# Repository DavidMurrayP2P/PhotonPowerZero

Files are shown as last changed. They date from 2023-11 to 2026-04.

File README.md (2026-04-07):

# PhotonPowerZero

The Photon Power Zero project aims to build an ecosystem of electronics, code, BoM and 3D printable parts that make it as easy as possible to go from a Raspberry Pi Zero proof of concept, sitting on someone's desk, to an outdoor deployment. The first 50 boards sold out through this [Kickstarter](https://www.kickstarter.com/projects/packets2photons/photon-power-zero).

You can find the user docs, showing you how to get started with the Photon Power Zero, and the design decisions around the board here:
* [USERDOCS](USERDOCS.md) 
* [6W SOLAR BUILD](FDM/6W_Voltaic_Panel_to_Multicomp_enclosure/README.md)
* [10W SOLAR BUILD](FDM/10W_Voltaic_Panel_to_Multicomp_enclosure/README.md)
* [REDUCING_ENERGY_CONSUMPTION](REDUCING_ENERGY_CONSUMPTION.md)
* [DESIGN_AND_DECISIONS](DESIGN_AND_DECISIONS.md)
* [LIPO_PURCHASING](LIPO_PURCHASING.md)

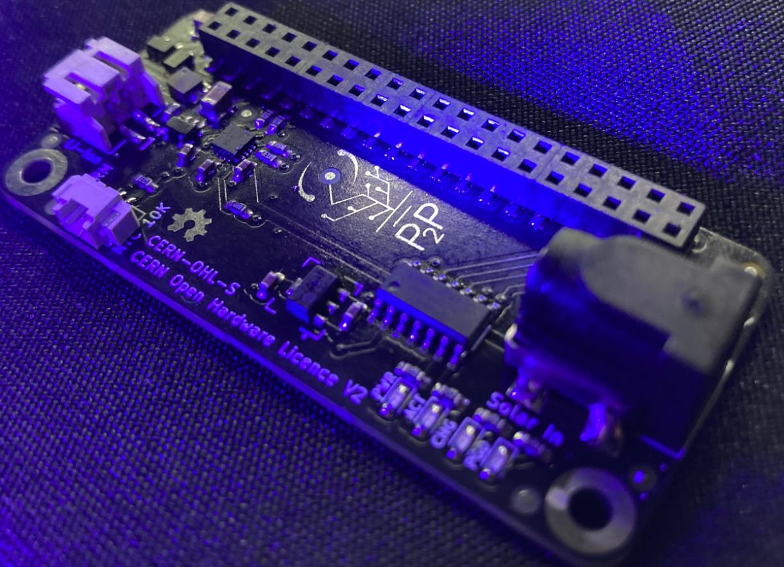
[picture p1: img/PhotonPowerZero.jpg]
Title
 <p style="text-align:center; font-style:italic;">Photon Power Zero Board</p>

The project is more than just the Photon Power Zero board. I want to create and share all components to make deploying a Raspberry Pi Zero outdoors as easy as possible. You can collaborate on the project and recieve support through the [Discord](https://discord.gg/BphNWmj6Xg)

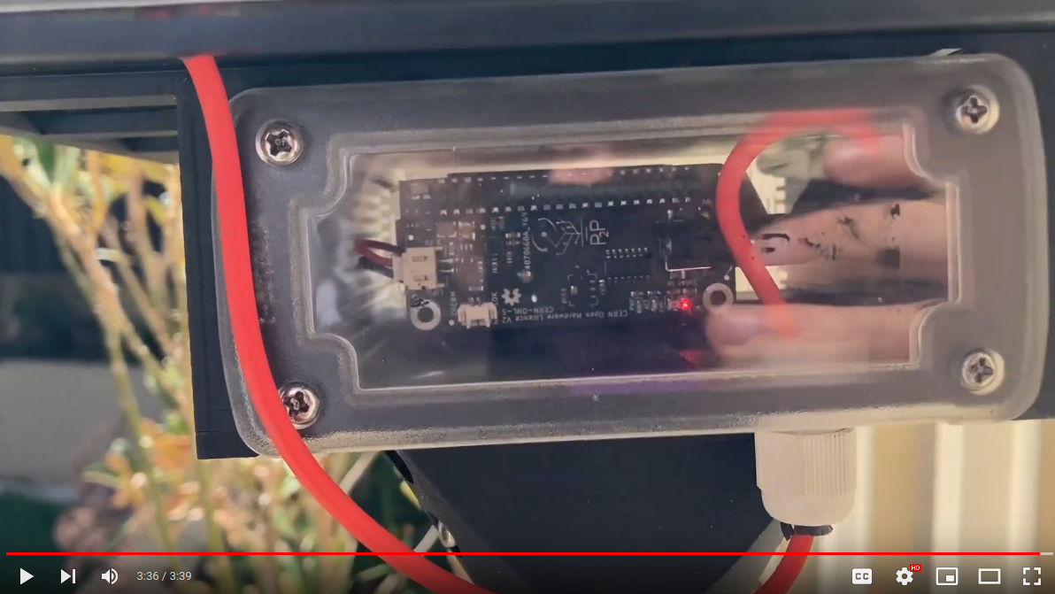
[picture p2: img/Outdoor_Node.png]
Video Thumbnail
 <p style="text-align:center; font-style:italic;">Youtube Video describing the Project and the goals</p>

As an open-source project, you can find the code for the Photon Power Zero and the Raspberry Pi, the Kicad PCB files and the FDM 3D printing files below
* [Code](Code)
* [PCBs](PCBs)
* [FDM (3D Print Files)](FDM)

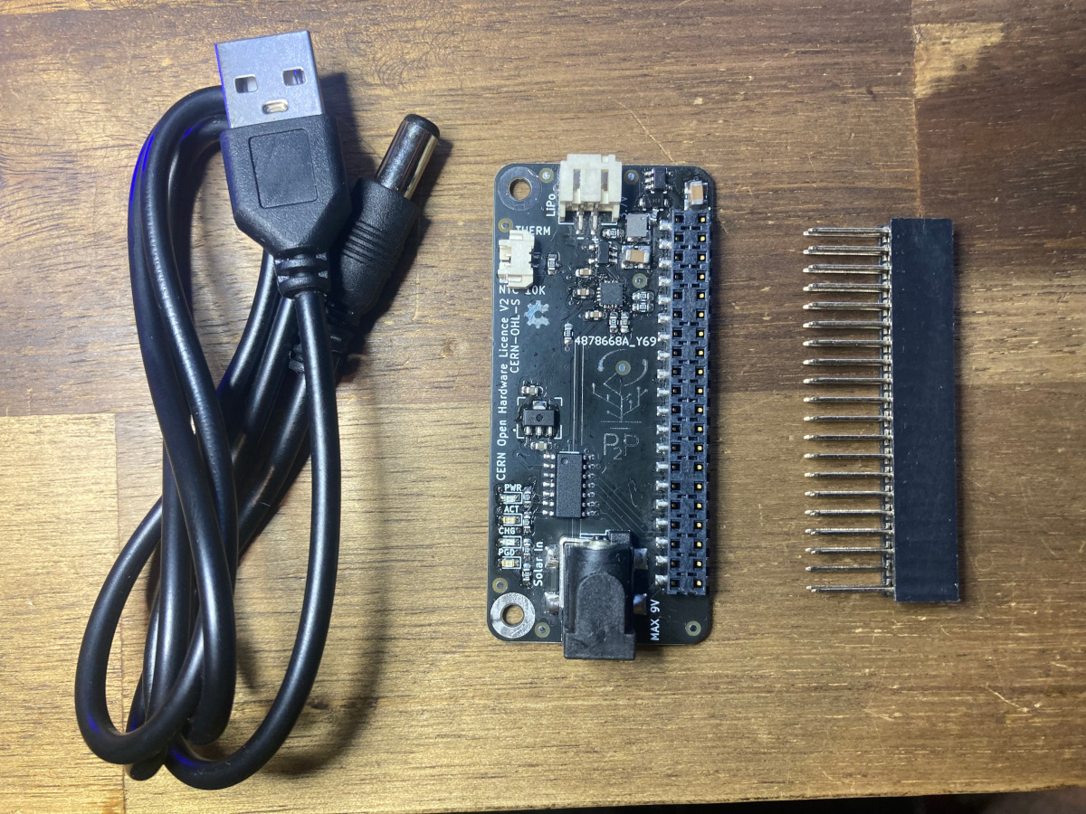
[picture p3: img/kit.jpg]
Production Kit Title

<p style="text-align:center; font-style:italic;">Production kit</p>

Note that the Photon Power Zero does not come with a LiPo battery. You need to self-source your battery and carefully read our [LIPO_PURCHASING](LIPO_PURCHASING.md) guide.

We have tested the solar panels from [Voltaic Systems](https://voltaicsystems.com/). We used the 6-watt 6-volt panels during testing, but now recommend the the 9-10-watt panels specified in the [10W SOLAR BUILD](FDM/10W_Voltaic_Panel_to_Multicomp_enclosure/README.md)

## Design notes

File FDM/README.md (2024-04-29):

# Photon Power Zero Mounts and Cases

The purpose of this section is to provide ways to mount your Raspberry Pi Zero and Photon Power Zero as well as provide mounts inside cases, batteries, solar panels, cameras and common acessories. 

In each of these subdirectories, there should be links to 3D printer files as well as instructions on how to print, and links to what should be purchased. 

The hope is that, as a community, we can suport a wide range of solar panels, batteries and water proof enclosures.

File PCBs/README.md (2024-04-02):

# PhotonPowerZero PCB

Title <p style="text-align:center; font-style:italic;">Photon Power Zero Board</p>

### BOM ###
 - 1k	4	https://www.digikey.com.au/en/products/detail/yageo/RC0603FR-071KL/726843
 - 10k	5	https://www.digikey.com.au/en/products/detail/yageo/RC0603JR-0710KL/726700
 - 1.13k	1	https://www.digikey.com.au/en/products/detail/yageo/RC0603FR-071K13L/726849
 - 1.18k	1	https://www.digikey.com.au/en/products/detail/yageo/RC0603FR-071K18L/726851
 - 10uf	6	https://www.digikey.com.au/en/products/detail/yageo/CC0805ZKY5V6BB106/2103093
 - Red 0603 LEDs	2	https://www.digikey.com.au/en/products/detail/liteon/LTST-C191KRKT/386837
 - Green 0603 LEDs	2	https://www.digikey.com.au/en/products/detail/rohm-semiconductor/SML-D12M8WT86/1641797
 - 100uf 1210	2	https://www.digikey.com.au/en/products/detail/samsung-electro-mechanics/CL31A107MQHNNNE/3887440
 - 2.2 µH Shielded Inductor 2.5 A 90mOhm Max 1210	1	https://www.digikey.com.au/en/products/detail/delta-electronics-cyntec/HMLE32251B-2R2MS/9761439
 - ATtiny84-SSFR	1	https://www.digikey.com.au/en/products/detail/microchip-technology/ATTINY84A-SSFR/3789533
 - AP2161-WG	1	https://www.digikey.com.au/en/products/detail/diodes-incorporated/AP2161WG-7/1964659
 - Diode 60 V 2A Surface Mount SOD-123F	1	https://www.digikey.com.au/en/products/detail/smc-diode-solutions/SK34A/6023036
 - REG_MCP1700T-3602E/MB	1	https://www.digikey.com.au/en/products/detail/microchip-technology/MCP1700T-3002E%2FMB/3622376
 - bq2407	1	https://www.digikey.com.au/en/products/detail/texas-instruments/BQ24074RGTR/2047269
 - TPS613222A	1	https://www.digikey.com.au/en/products/detail/texas-instruments/TPS613222ADBVT/9371270
 - SMT_Solar_barrel	1	https://www.aliexpress.com/item/32730853300.html
 - JST_S2B-PH-SM4-TB_LF__SN_	1	https://www.aliexpress.com/item/4000906681691.html
 - Barrel Jack to USB	1	https://www.aliexpress.com/item/1005003706471183.html
 - Samtech Pi headers	1	https://www.samtec.com/ HLE-120-02-L-DV-BE-A-K
 - Raspberry Pi header extender	1	https://www.aliexpress.com/item/4001267078607.html

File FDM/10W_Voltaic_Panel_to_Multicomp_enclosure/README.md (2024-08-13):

# 10W Voltaic Solar Panel to MULTICOMP PRO MC002194 enclosure

This guide shows you how to build a 10W outdoor solar mount for your Raspberry Pi Zero and Photon Power Zero.

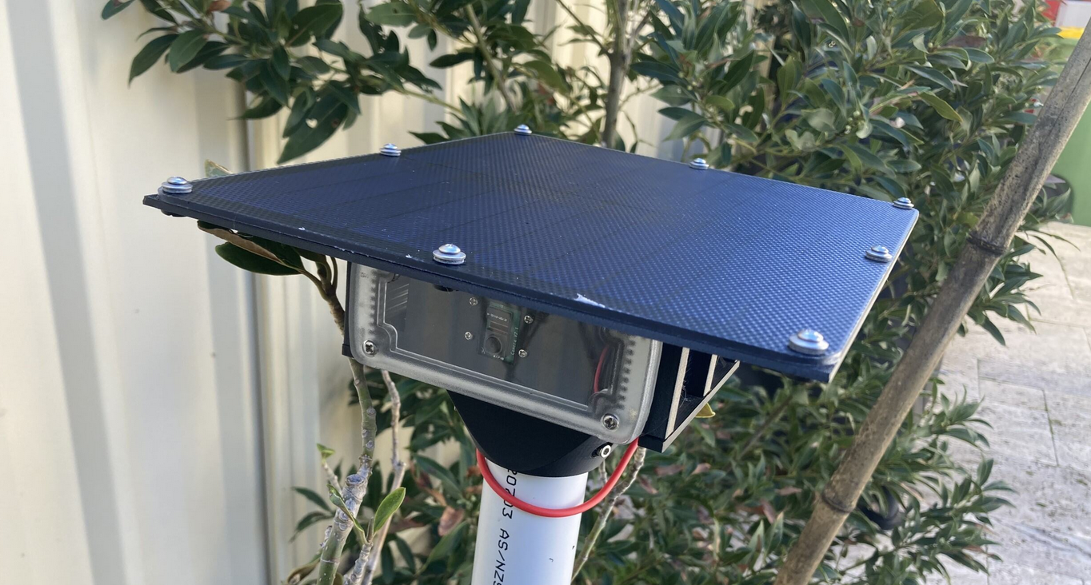
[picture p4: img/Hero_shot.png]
<p style="text-align:center; font-style:italic;">Finished construction</p>

This is a panel mount for Voltaic's 10W solar panel. These have been printed and tested using ABS, but other materials may work well too. ASA will almost certainly be as good. I also think that PETG will likely work, but this is untested. There is a [Bill of Materials (BOM)](#bill-of-materials-bom) which links to multiple sources, at the bottom of the page. All the files required for printing can be found here [10W Voltaic Panel to Multicomp enclosure](https://github.com/DavidMurrayP2P/PhotonPowerZero/tree/main/FDM/10W_Voltaic_Panel_to_Multicomp_enclosure).

The image below shows the entire stet of printed parts but they must be printed in multiple parts. How many parts will depend on your printer size.

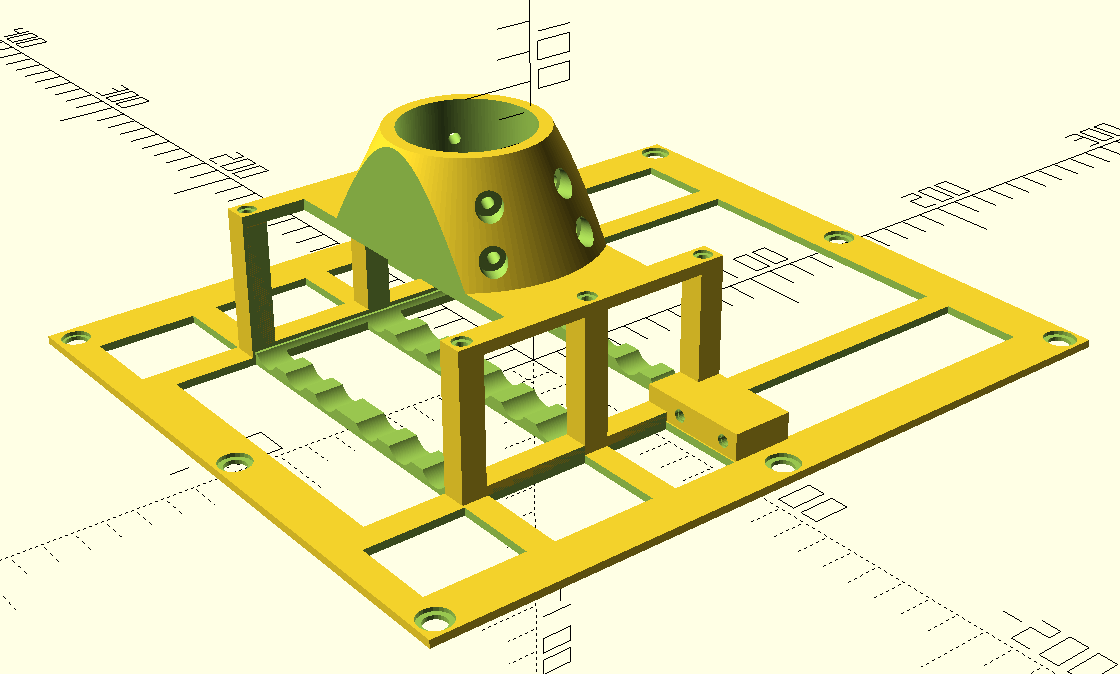
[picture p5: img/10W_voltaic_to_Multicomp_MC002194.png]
<p style="text-align:center; font-style:italic;">Connect the 10W volatic Panel to the Mutlicomp MC002194 Enclosure and 25mm OD PVC Pipe. This is obviously printed in two parts. 

The image above shows what the mount looks like
Title<p style="text-align:center; font-style:italic;">Finished construction
 but you can print it in two parts. This should be divided up for you already in the files pole_mount.stl and Panel_Mount_10W.stl

Most people will need to print the Panel_Mount_10W.stl in two parts: Panel_Mount_10W_1st_half.stl and Panel_Mount_10W_2nd_half.stl

When you print these parts, you will need to sink the brass heat set inserts:

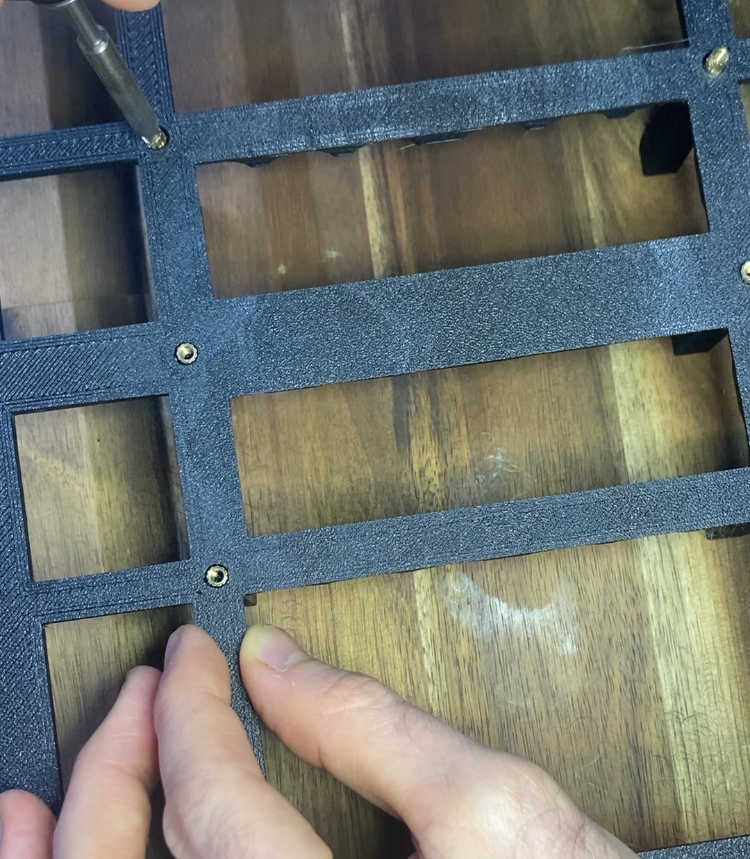
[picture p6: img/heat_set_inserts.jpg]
<p style="text-align:center; font-style:italic;">You will need to put 6 heat set inserts in the bottom side of the panel mount

After you do this you will most likely need to clean out the holes. I like to put the m3 screws in on the opposite side to force any plastic out and clear the path.

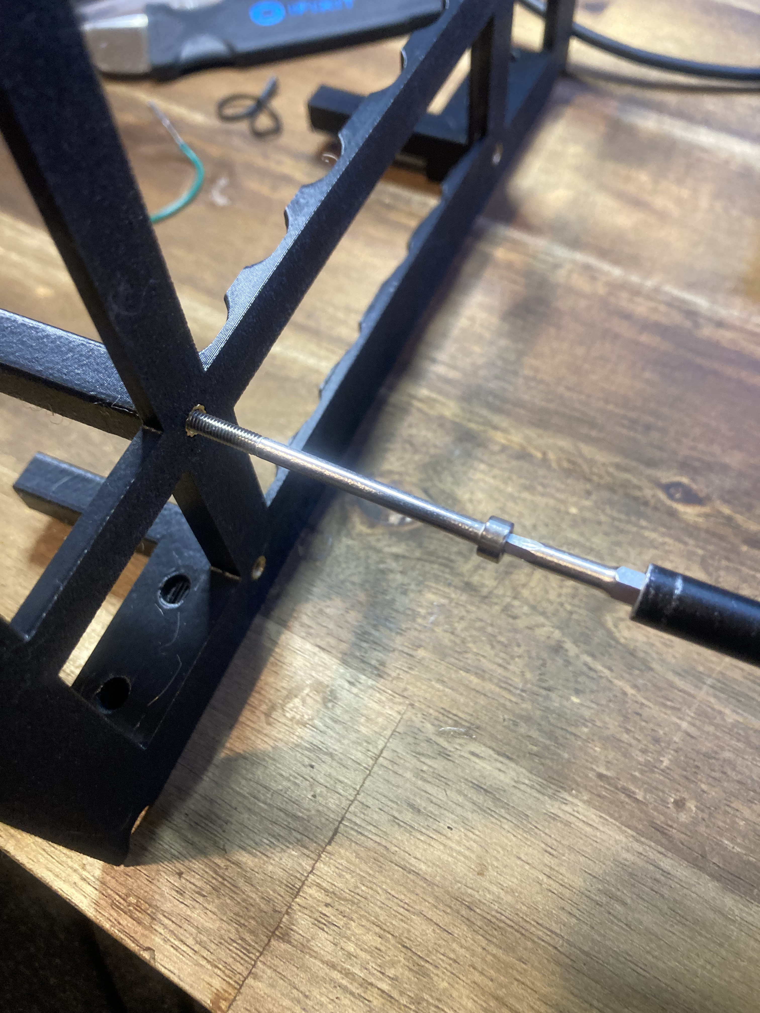
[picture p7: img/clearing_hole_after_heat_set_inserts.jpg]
<p style="text-align:center; font-style:italic;">Make sure you clear the holes by putting m3 screws in the wrong way around.

You have likely printed the panel mount in two parts. They screw together with M3 heat set inserts and M3 screws.

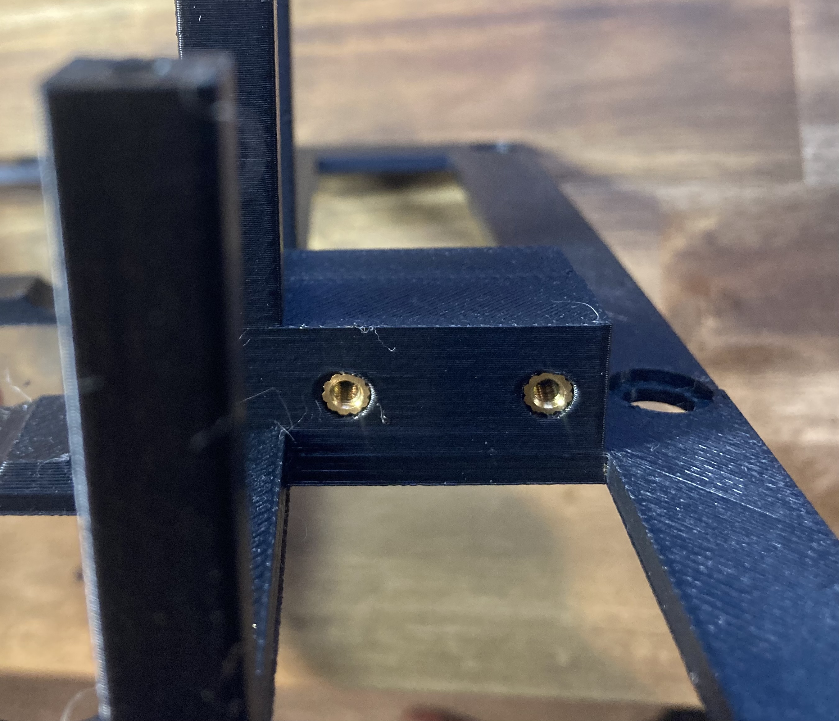
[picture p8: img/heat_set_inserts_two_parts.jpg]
<p style="text-align:center; font-style:italic;">Heat set inserts for the two parts

You can then srcew the two parts together:

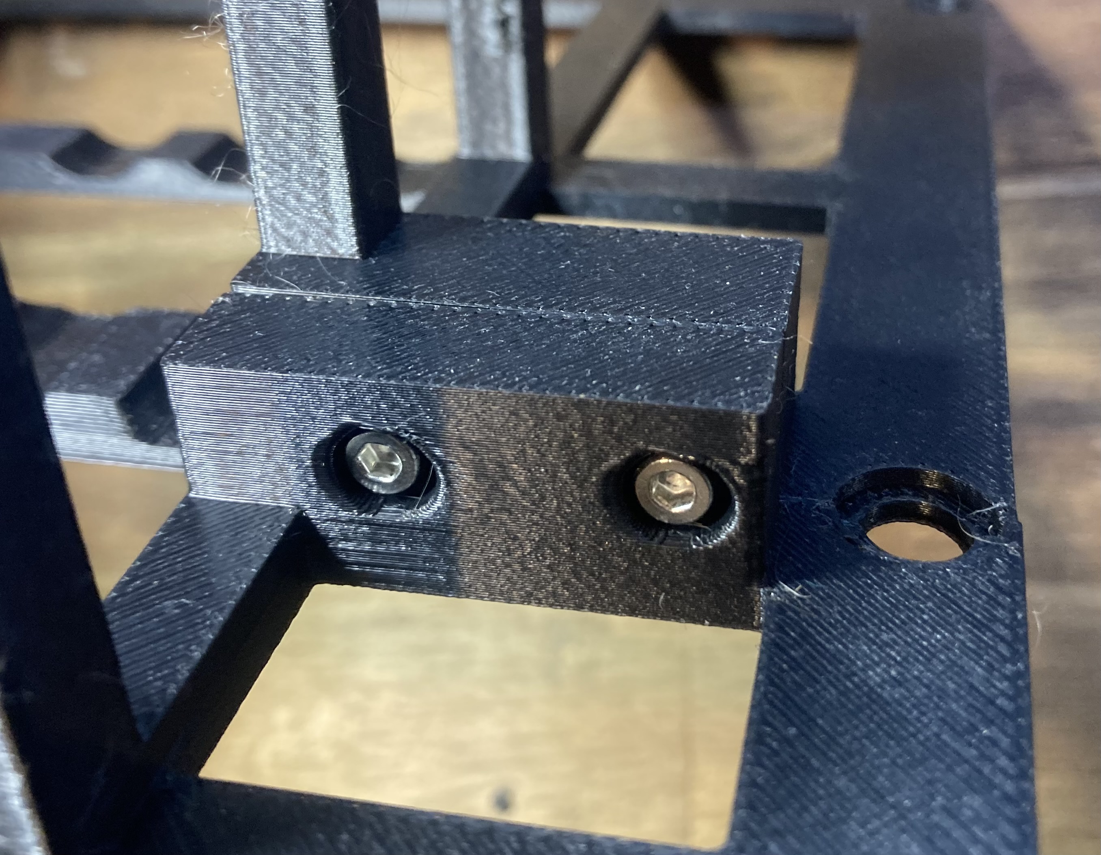
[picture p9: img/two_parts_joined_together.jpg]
<p style="text-align:center; font-style:italic;">Screw the two parts together

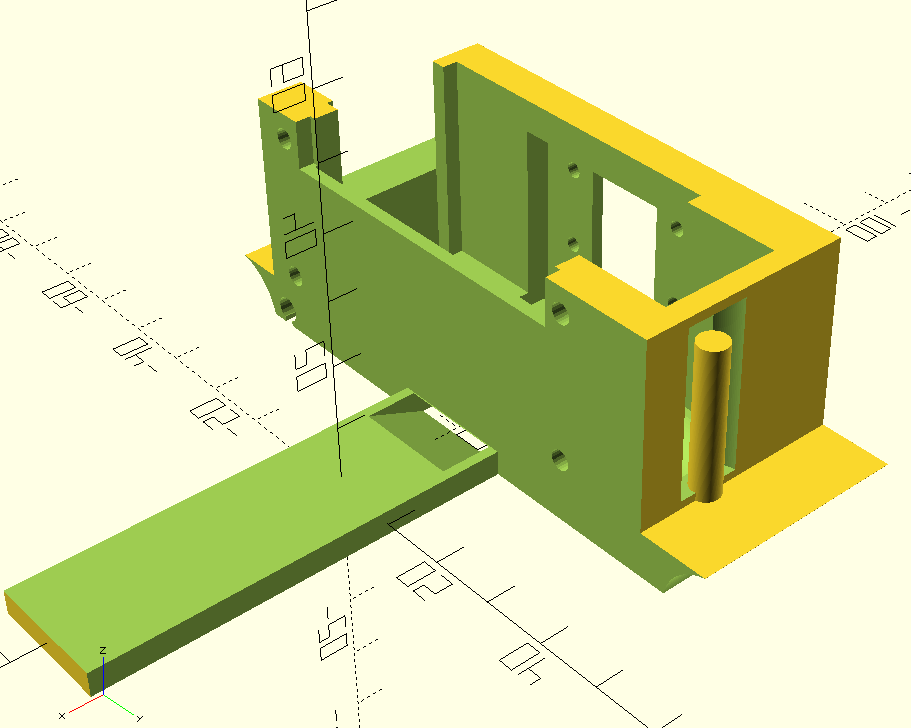
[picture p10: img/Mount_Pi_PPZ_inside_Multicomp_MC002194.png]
<p style="text-align:center; font-style:italic;">Mount inside the Multicomp MC002194 Enclosure

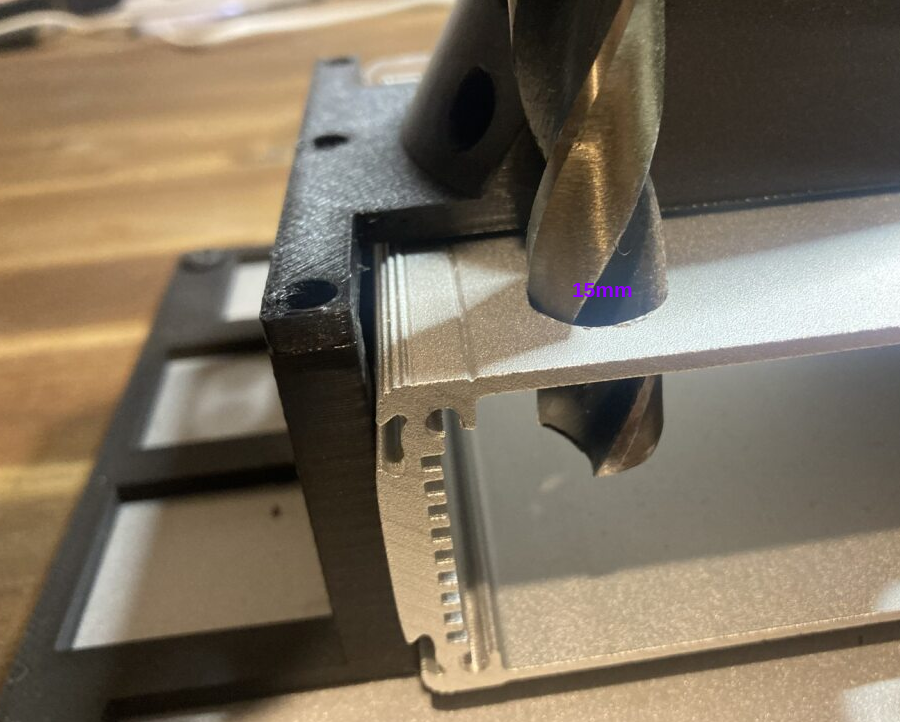
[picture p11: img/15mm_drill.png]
<p style="text-align:center; font-style:italic;">You need to drill a 15mm hole in the aluminium and use a Waterproof cable gland PG-9. Obviously you don't drill this hole on top of the solar pannel.

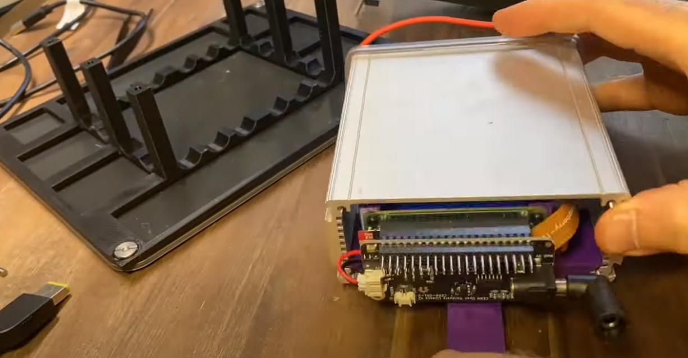
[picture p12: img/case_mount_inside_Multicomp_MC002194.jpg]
<p style="text-align:center; font-style:italic;">The case mount goes inside the multicomp

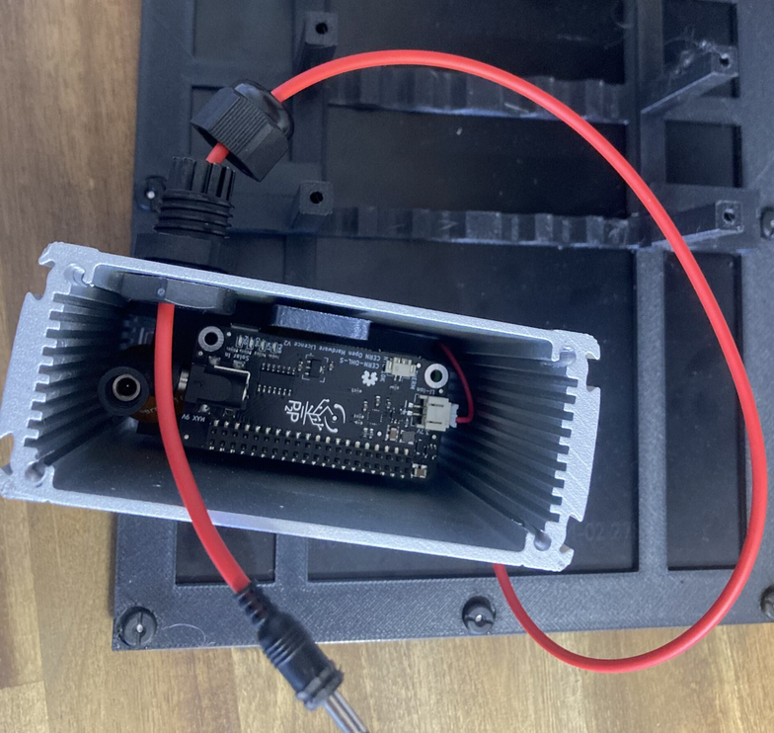
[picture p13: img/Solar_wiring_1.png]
<p style="text-align:center; font-style:italic;">Wiring the solar

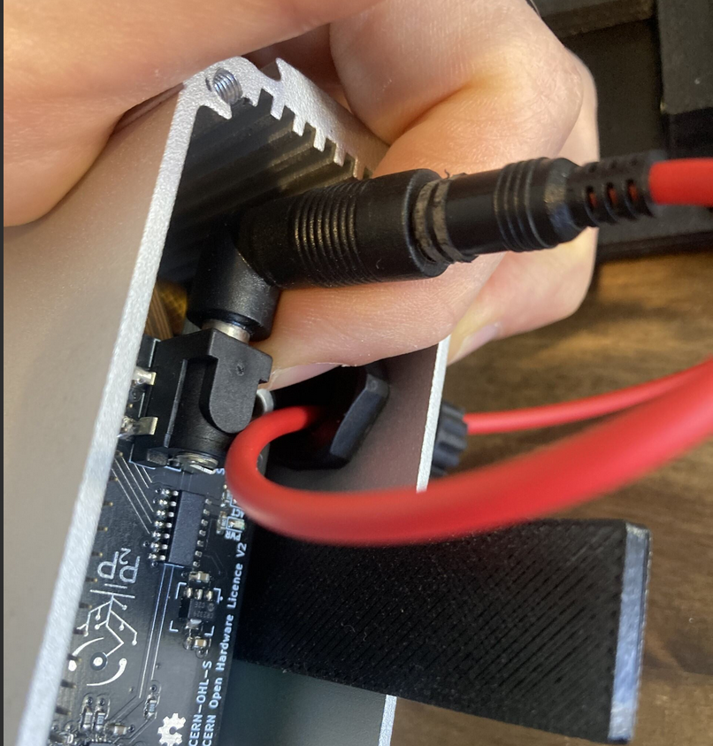
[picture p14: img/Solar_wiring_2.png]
<p style="text-align:center; font-style:italic;">Provide support for the connector while you plug it in

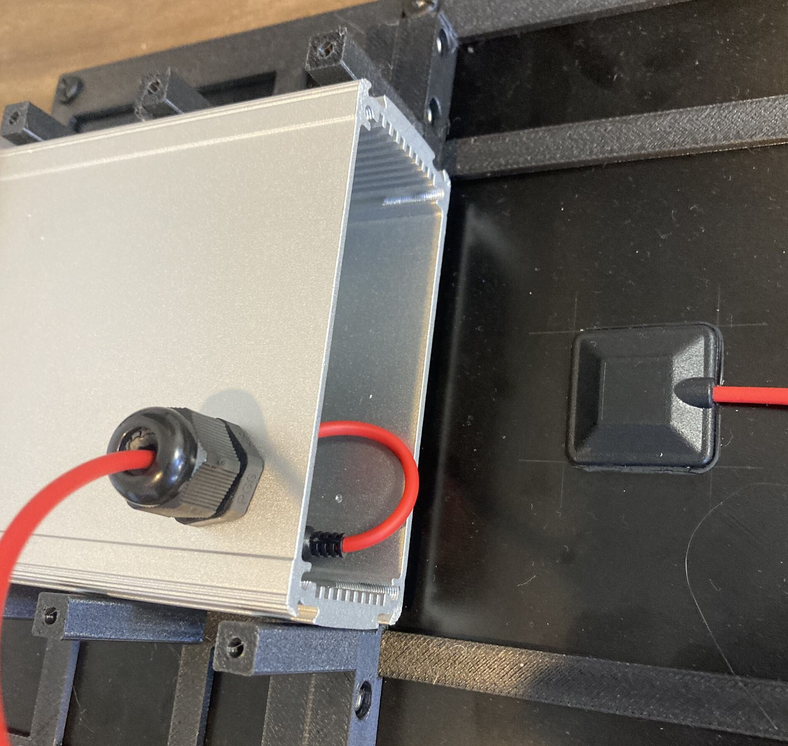
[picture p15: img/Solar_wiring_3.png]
<p style="text-align:center; font-style:italic;">Tighten the PG-9 Gland

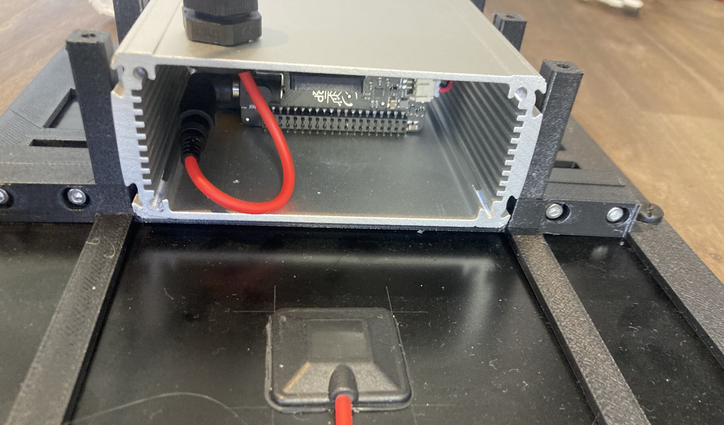
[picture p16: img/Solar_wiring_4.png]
<p style="text-align:center; font-style:italic;">In the next step we will screw the plastic end on

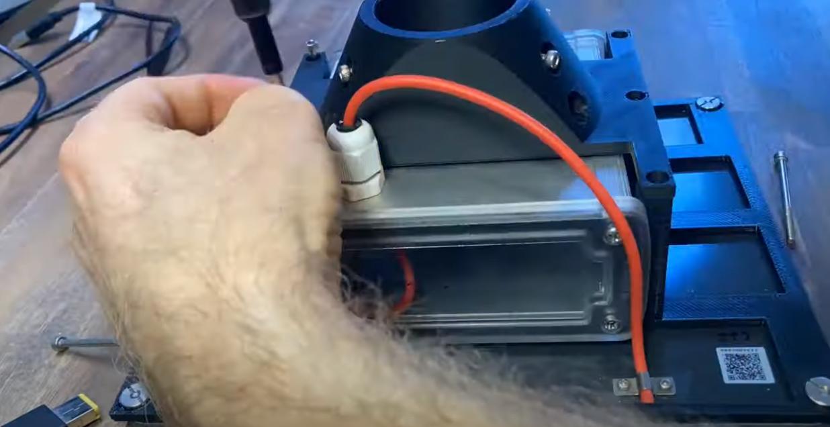
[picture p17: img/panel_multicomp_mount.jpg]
<p style="text-align:center; font-style:italic;">Physically Fitting it together, put a 25mm PVC pipe to connect the structure to the soil or a Ubolt clamp
panel_multicomp_mount.jpg

Use 50mm M3 screws to put screw pole_mount.stl into the panel mount.

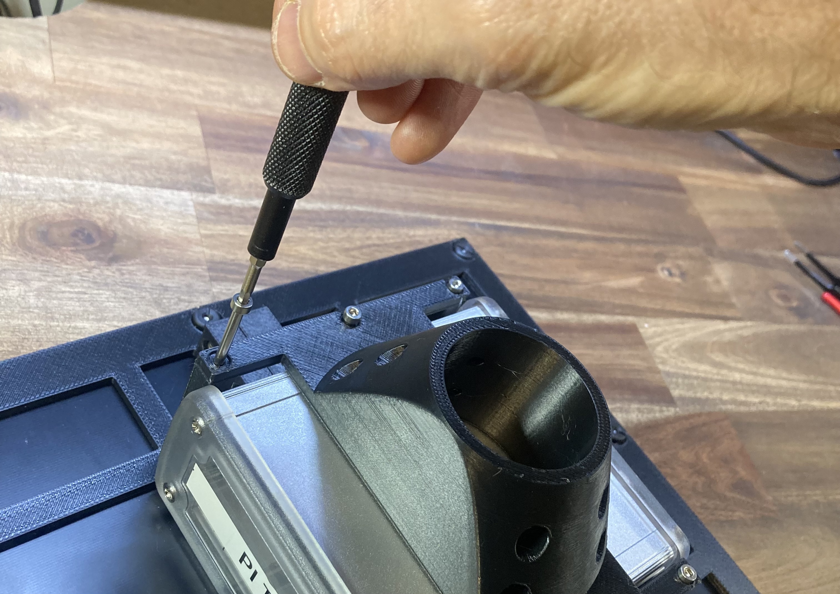
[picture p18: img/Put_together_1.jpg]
<p style="text-align:center; font-style:italic;">Use 50mm M3 screws to put screw pole_mount.stl into the panel mount.

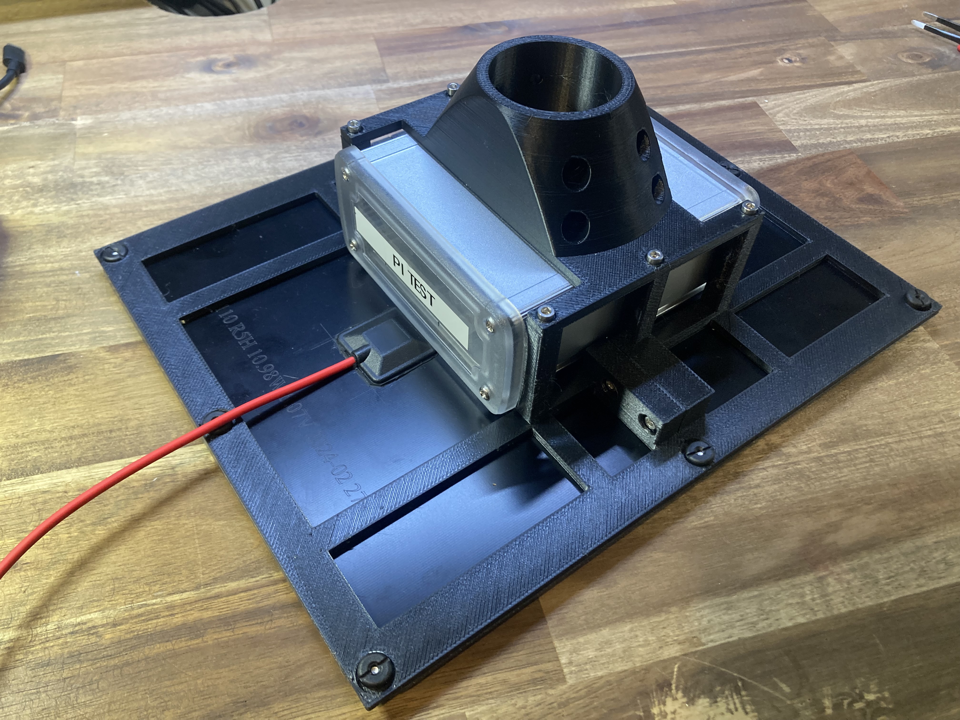
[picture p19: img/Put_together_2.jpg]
<p style="text-align:center; font-style:italic;">Screwed together

## Bill of Materials (BOM)

#### MULTICOMP PRO MC002194 
Metal Enclosure, Small, Extruded Aluminium, 51.6 mm, 119 mm, 115.1 mm Links:
- https://www.jaycar.com.au/aluminium-enclosure-with-clear-ends/p/HB6294
- https://il.farnell.com/multicomp/mc002194/multipurpose-enclosure-alum-silver/dp/2830527
- https://www.newark.com/multicomp-pro/mc002194/enclosure-4-53-x-4-69-x-2-03/dp/57AC8361
- https://www.devicemart.co.kr/goods/view?no=12072777
- https://dk.farnell.com/en-DK/multicomp/mc002194/multipurpose-enclosure-alum-silver/dp/2830527

#### Fixing hardware 

These are for mounting the Raspberry Pi Zero to the case inside the enclosure
 - 4x M2.5 heat set inserts like https://www.aliexpress.com/item/1005004535859664.html
 - M2.5 Mounting hardware https://www.aliexpress.com/item/1005004275784627.html
  - Waterproof Cable Gland https://core-electronics.com.au/cable-gland-pg-9-size-0-158-to-0-252-cable-diameter-pg-9.html OR https://www.adafruit.com/product/761
  
These are for bolting pole_mount.stl and Panel_Mount_10W.stl together. 
  -  6 x M3 heat set inserts OD 5mm Length ~8mm https://www.aliexpress.com/item/1005004535859664.html - These go on the underside of the panel fitting
 - 6 x M3 50mm Staintelss steel hex bolt https://www.thefastenerfactory.com.au/stainless-steel-hex-socket-head-cap-screw-m3-x-50mm-100pc

#### 10W Voltaic Panel

 - Solar Panel https://voltaicsystems.com/10-watt-panel-etfe/ OR https://www.adafruit.com/product/5369 OR https://core-electronics.com.au/5v-10w-solar-panel-etfe-voltaic-p110.html
 - Right angled Female 3.5x1.1mm - 5.5x2.1mm: https://voltaicsystems.com/A106 or https://www.adafruit.com/product/4287
 - If you get an EFTE panel you need to get ETFE Panel Screw & Washer Set https://voltaicsystems.com/mount-set-etfe/ these are 4-40 but an M3 should work

## Finished Construction

The 25mm PVC pipe can go in the ground or you could use a UBolt. You can modify the scad to support any size round post that you like.

Title<p style="text-align:center; font-style:italic;">Finished construction

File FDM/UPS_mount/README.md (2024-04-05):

# Photon Power Zero 3D Prints 

All of these Parts are designed to be printed in ABS or better. You may print is PLA if your use case is indoor only but otherwise, the reccomendation is ABS.

## Indoor UPS
 - 4x M2.5 heat set inserts like https://www.aliexpress.com/item/1005004535859664.html
 - M2.5 Mounting hardware https://www.aliexpress.com/item/1005004275784627.html
 - USB to barrel Jack cable: https://www.aliexpress.com/item/1005003706471183.html
 - See LiPo instructions below

image1

## Outdoor Solar Node

### Enclosure

 - 4x M2.5 heat set inserts like https://www.aliexpress.com/item/1005004535859664.html
 - M2.5 Mounting hardware https://www.aliexpress.com/item/1005004275784627.html
 - Aluminium Enclosure https://www.jaycar.com.au/aluminium-enclosure-with-clear-ends/p/HB6294

### Solar Panel and Mount
Image 3

 - 6 x M3 heat set inserts OD 5mm Length 10mm https://www.aliexpress.com/item/1005004535859664.html
 - 6 x M3 50mm Staintelss steel hex bolt https://www.thefastenerfactory.com.au/stainless-steel-hex-socket-head-cap-screw-m3-x-50mm-100pc
 - Solar Panel https://voltaicsystems.com/6-watt-panel/

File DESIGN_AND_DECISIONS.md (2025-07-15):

# Design and Decisions

This document describes the fundamental design decisions of the Photon Power Zero. This project started in late 2022 because I wanted to solar power a Raspberry Pi. The Raspberry Pi is not class-leading in terms of efficiency or power management, but it is still the best supported Single Board Computer (SBC) with the widest availability of compatible sensors. The Photon Power Zero is a Raspberry Pi Zero HAT that slides over the top of the Raspberry Pi, manages power, and makes solar charging possible, and  addresses, in my opinion, one of the Raspberry Pi's biggest deficiencies; power management.

## Design

You can review the schematic and the board layout, but this section will provide a mile-high overview of this project. The Photon Power Zero is designed around the [BQ2407](https://www.ti.com/lit/ds/symlink/bq24074.pdf) chip and handles the 5-9v input from a USB or a solar panel. It will prioritise powering the ATtiny84 microcontroller, which is the brains of the board. The ATtiny84 is clocked down to 1MHz and consumes little power. This ATtiny84 monitors the LiPo battery voltage through a voltage divider on an ADC pin. When the power level of the battery is high enough, it will pull the enable pin on the AP2161-WG, a high side switch, low. When this switch is pulled low, it will power a 5V DC Boost circuit TPS613222A to power the Raspberry Pi at 5V.

The ATtiny84 is connected to pins on the Raspberry Pi Zero that are rarely used on other Pi HATs. One pin is used to flag that the Raspberry Pi should gracefully shut down. Other pins are used to bit-bang a battery voltage number to the Raspberry Pi. You can read the C code used on the ATtiny to get a better understanding of when the Raspberry Pi will switch on and off.

## Does it work for the Raspberry Pi 3/4/5 or Jetson

These platforms use a lot more power and would require a bigger battery, solar panel and likely a board redesign. Even good quality 2-pin LiPo Batteries often come with wires that only support 1 Amp. This will be a limiting factor on both the charge rate and the current draw when being used. A completely different design would be required to support the 2-5 Amps needed for these more powerful boards.

There is also the problem of heat. Both electronics and batteries perform much better when cool. Subjecting them to outdoor temperatures is challenging. If your panels are going to work, they need to be in the sun. The approach I have taken is to use the solar panel as the shade and to try to maintain an air gap between the panels and the enclosure for the weatherproof container; the solar panel will be very, very hot on a 40-degree Celsius day. Adding a Raspberry Pi 3/4/5 or Jetson Nano project and keeping them in a sealed container with a LiPo battery is likely to see dramatic thermal throttling and a heavily reduced lifespan. This board doesn't support this, and I wouldn't recommend this approach.

## Does this measure LiPo Battery temperature

Yes and no. So, an NTC thermistor can be added. There is a recommendation in the [BQ2407](https://www.ti.com/lit/ds/symlink/bq24074.pdf) documentation. To use this, you must purchase a thermistor that fits into the JST connector. You would also need to desolder the nearby 10k resistor.

By intentional design, the charge current for the battery is always limited to under 1 amp. Given the limited 1 amp charging speed over a 4400mAh battery, we have not found the use of a thermistor necessary, and we have months of testing over at 44C ambient temperature days. Any additional heat generated through charging is negligible compared to the ambient temperature.

## Can I solder my own solar pannel leads to this board

A revision 2 is underway to potentially allow this, however, I think that a lower risk approach is to use the cable provided with your board or to make use of an existing barrel jack cable and to join the leads on your solar pannel to an existing barrel jack cable. I think this is more likely to be successful for most people. Twist the wires, add a little solder to the joint and use some good quality heat shrink tubing.

## Pins in use

The diagram below shows which of the Raspberry Pi Pins are used by the Photon Power Zero.

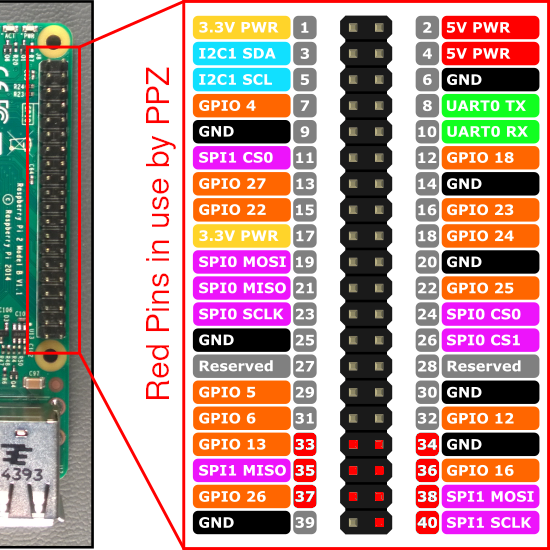
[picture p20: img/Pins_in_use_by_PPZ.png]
Title
<p style="text-align:center; font-style:italic;">These are the pins in use by the Photon Power Zero

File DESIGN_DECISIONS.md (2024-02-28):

# Design Decisions

This document describes the fundamental design decisions ofthe Photon Power Zero. This project started in late 2022 because I wanted to solar power a Raspberry Pi. The Raspberry Pi is not class leading in terms of power efficiency or power managment, but it is class leading in terms of software support of the operating system and avaliabilyt of compatible sensors. A HAT that sits on the top of the Raspberry Pi, and manges power, and makes solar charging possible addresses one of the Raspberry Pi's deficiencies.

## Does it work for the Raspberry Pi 3/4/5 or Jetson

These platforms use a lot more power and would require a bigger battery, solar pannel and likely a board redesign. Even good quality 2 pin LiPo Batteries often come with wires that only support 1 Amp. This will be a limiting factor on both the charge rate as well as the current draw when being used. The design required to support the 2-5 Amps required by these more powerful boards.  

There is also the problem of heat. Both electronics and batteries perform much better when cool. Subjecting them to outdoor temperatures is challenging. If your panels are going to work, they need to be in the sun. The approach I have taken is to use the solar pannel as the shade and to try to maintain an air gap between the panels and the enclosure for the weather proof container; the  solar pannel will be very very hot on a 40 Degree Celcius day. Adding a Raspberry Pi 3/4/5 or Jetson nano project and keeping them in a sealed container with a LiPo battery is asking to have a bad time. This board doesn't support this and I wouldn't reccomend this approach.

## Does this measure LiPo Battery temperature

Yes and no. So there is the ability to add a NTC thermistor. There is a recommendatinos in the [BQ2407](https://www.ti.com/lit/ds/symlink/bq24074.pdf) documentation. To make use of this you would need to purchase a thermistor that fits into the JST connector left for use. You would also need to desolder the nearby 10k resistor.

By intentional design, the charge current for the battery is always limited to under 1 amp. Given this charge speed over a 4400mAh battery, we have not found the use of a thermistor to be necessary, and we have months of testing over at on 44C ambient temperature days. Put simply, the heat added through charging in negligible in comparison to the ambient temperature.

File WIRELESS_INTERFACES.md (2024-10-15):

# WIRELESS INTERFACE OPTIONS

### This page is incomplete and is a work in progress

The purpose of this page is to document the different Wireless interface options that are avaliable on the raspberry pi, past the inbuilt WiFi and Bluetooth. 

As you know the goal of this project is to make it as easy as possible to deply outdoor computing. We want to be able to easily deploy outdoor single board computers and have sensors or cameras report information back. A large comonent of this is networking and having wireless interfaces that ensure that we can collect the data over a wireless interface. 

This page reviews the options and provides the code to make them work. The goal of this project is to make it as easy as possible. We want the network interface to be low power, with a goal of the network interface is to use less than 5V x 0.1 Amps 0.5W on standby and 5V x 0.15 Amps 0.75W while transmitting. With the Raspberry Pi Zero, this means that we are aming fro less than 5v 0.25 Amps total which is 1.25 Watts in total. Going beyond this we will have implications for batteries and solar pannels.

We also want this to be easy. So Ideally, this should be easy to connect to an IP or IPv6 network. I think that the ideal technology in this space, will likely be 6LowPAN. While this has historically been used for 802.15.4 networks it can be used with sme of the Sub-GHz ISM band radios.

Finally, the solution should cost under 40USD. This is not a hard requirement, initially higher costs are tolerable if there is the opportunity for reduced costs in the future with volume.

Speeds should be in the 50-200Kb/s range. The goal is not to stream live video, but we should be at least able to move a 350KB image within 60 seconds. So 350KB is 2800 bytes. If the link supports 50Kb/s then 2800/50 = 56 seconds.

The following is an attempt to evaluate what is currently out there on the market.

## Design Criteria

The goal of this is to provide you with the information you might need if you are deploying a low power solar powered Rasberry Pi Zero. As you can see below, the Raspberry Pi Zero runs at 5V and 0.1 amps which is 0.5W when idle. The design criteria is to stay under 0.2 Amps when Idle and under 0.25 amps when transmitting data. These are my goals for heat and battery life reasons. Be aware that in the [Reducing Energy Consumption](REDUCING_ENERGY_CONSUMPTION.md) document, the power consumption of the Pi Zero 2W was about 25% higher at idle speeds. These are very much ballpark numbers however.

# Options

 - [Cellular Options](#Cellular-Options)
	- [The SIM7600X 4G HAT](#the-sim7600x-4g-hat)
    - [SIMCOM-7020E](#SIMCOM-7020E) NB-IoT
    - [SIMCOM-A7670SA](#SIMCOM-A7670SA) LTE Cat1 Module

 - [LoRaWAN options](#LoRaWAN-Options)
   - [RAK2245](#RAK2245) - Pi HAT 8 Channel LoRaWAN module SX1301
   - [RAK811](#RAK811) LoRaWan End Device

 - [Other Options](#Other-Options)
    - [NRF24](#NRF24)
    - [RFM69HCW](#RFM69HCW)

## Cellular Options

### The SIM7600X 4G HAT

The SIM7600X 4G HAT is a great fit for the Pi. The form factor is great. It appears to work over USB, using spring pins to hit VCC, GND, D+ and D-. You can see the idle power consumption as well as the power consumption under load below. This is a very good module however the price as well as the power consumption are both highert than I would like to see.

Here is the idle power consumption:

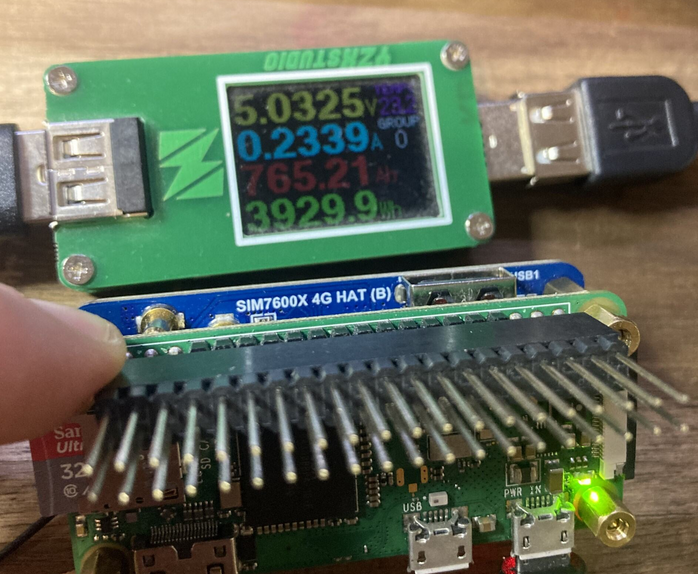
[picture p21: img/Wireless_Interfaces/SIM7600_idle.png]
 <p style="text-align:center; font-style:italic;">Raspberry Pi Zero Rough Idle power conspmption </p

#### Config

Check if the Modem is Detected:

```
sudo mmcli -L
```

Enable and Configure the Modem:

```
sudo mmcli -m 0 --enable
sudo mmcli -m 0 --simple-connect="apn=YOUR_APN"
Replace YOUR_APN with your carrier's APN.
```

You can create a new connection using NetworkManager.

```
sudo nmcli connection add type gsm ifname cdc-wdm0 con-name gsm connection.autoconnect yes apn YOUR_APN
```
Connect to the Network:
```
sudo nmcli connection up gsm
```

Once connected, you should see the wwan0 interface with an IP address like below:

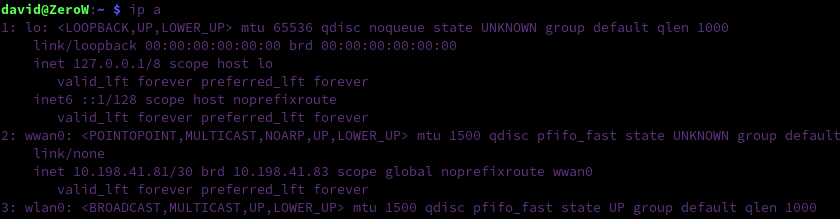
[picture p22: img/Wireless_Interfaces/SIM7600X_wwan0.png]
 <p style="text-align:center; font-style:italic;">Raspberry Pi Zero Rough Idle power conspmption </p>

This is the power consumption when lightly loaded.

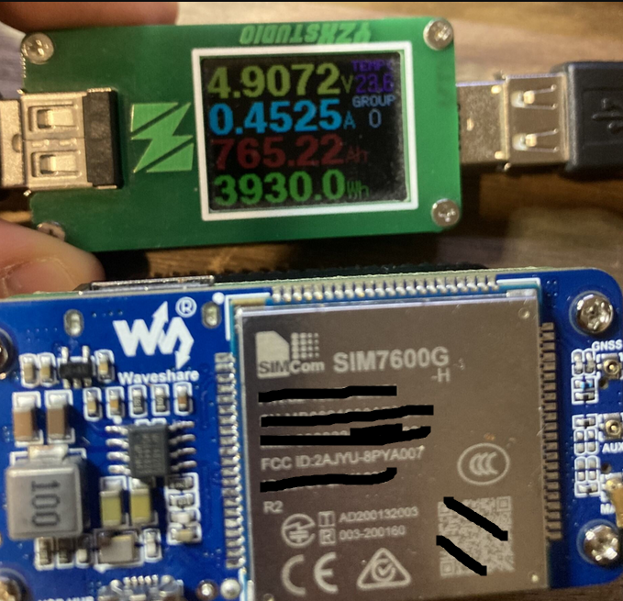
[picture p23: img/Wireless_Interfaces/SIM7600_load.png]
 <p style="text-align:center; font-style:italic;">Raspberry Pi Zero Rough Idle power conspmption </p>

Note that this is just a lot higher than we would ideally like to see. 

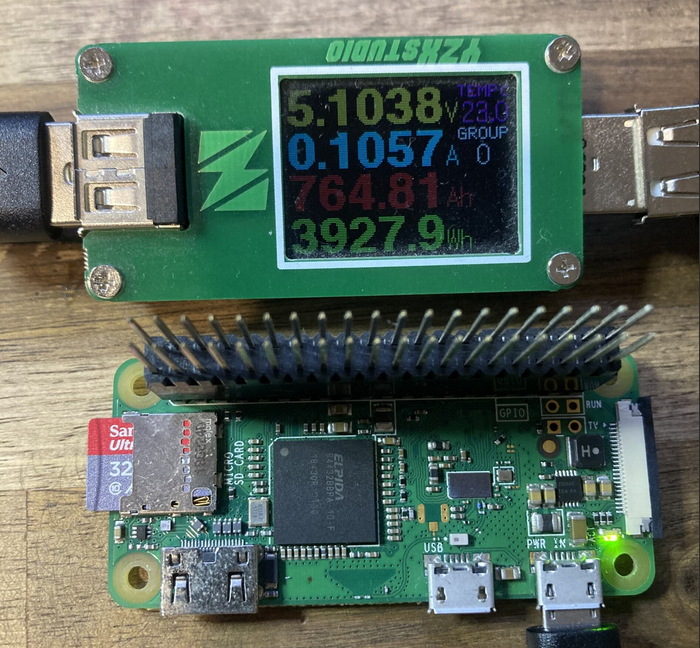
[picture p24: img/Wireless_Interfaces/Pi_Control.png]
 <p style="text-align:center; font-style:italic;">Raspberry Pi Zero Rough Idle power conspmption </p>

### SIMCOM-7020E

This looked exceptionally convenient as the form factor was already Raspberry Pi Zero sided and the headers matched up, eliminating any wiring. I had hoped that this might just work with regular sim card but unfortuately this needs an NB-IoT specialised sim card.

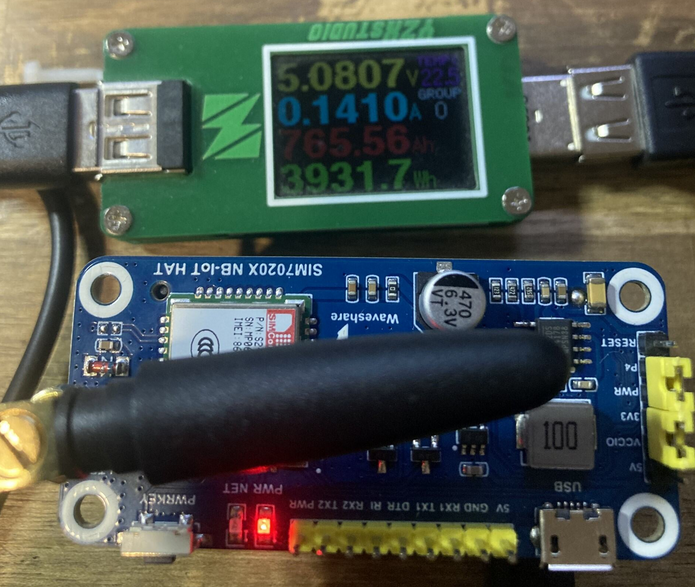
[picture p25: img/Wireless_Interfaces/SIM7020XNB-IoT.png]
 <p style="text-align:center; font-style:italic;">The power consumption of the SIMCOM-7020E</p>

### SIMCOM-A7670SA 
##### LTE Cat1 Module

I was excited to try this device because it was sold as supporting LTE Cat 1, but this did not recognise a regular sim. I will keep investigating this module but an initial look did not seem promising. This also only supported serial communications.

This did not work with my regular cheap phone sim.

Setup is pretty simple

```sudo raspi-config```

Navigate to Interfacing Options -> Serial. When prompted, select No to disable the serial console, then select Yes to enable the serial port hardware.

```sudo apt install minicom```

On the serial, try a:

```AT```

Then test if a SIM card has been inserted and detected:

```AT+CPIN?```

This will confirm that the modem is responding. Then: 

```AT+CGDCONT=1,"IP","telstra.m2m"```

Enable the network connection:

```AT+CIICR```

Get the IP address assigned to the module:

```AT+CIFSR```

![Alt text](img/Wireless_Interfaces/SIMA7670SA.png?raw=true "Title") <p style="text-align:center; font-style:italic;">The power consumption of the SIMCOM-A7670SA </p>

## LoRaWAN Options

### RAK2245
##### Pi HAT 8 Channel LoRaWAN module SX1301

I ran a Chiprstack Gatway in hot conditions for many years. I powered this device you can see below with a cheap Ali Express style PoE to usb power plug. 

This is the power consumption after booting:

![Alt text](img/Wireless_Interfaces/RAK2245.png?raw=true "Title") <p style="text-align:center; font-style:italic;">The Raspberry Pi Zero is underneath this RAK2224 concentrator.

This RAK2245 worked very well for long periods of time using the Chirpstack Gateway software. You can check out the latest versions here: https://www.chirpstack.io/docs/chirpstack-gateway-bridge/install/raspberry-pi.html This is a concentrator and will act as a LoRaWAN gateway for your deployment of LoRa devices. 

I genuinely had success with this device but when using this device I wal powering it through A PoE to USB plug similar to this: https://www.aliexpress.com/item/33035428356.html

This is a reasonable option for those wanting a Pi and a LoRaWAN gateway but the power draw is too high for solar and battery with the Photon Power Zero.

### RAK811

These LoRa end device modules work very well. I have had over 4km of reliable  transmit range using these. They do not consume excessive power and they were relatively cheap to buy. These seemed to be well designed and I could move binary data over these modules. The issue is that they are limited in speed by bothe technology, the LoRa standard operates down to vely impressive sensitiviy limits. Furthermore, they are also limited by regulation and in many parts of the world, these devices suffer from duty cycle limits. 

While adhereing to Australian limits, we have slowly moved heavily compressed images over these devices, it's not possible in most parts of the world and these will not be faste enough for a real network inteface in Linux, one of the original goals.

![Alt text](img/Wireless_Interfaces/RAK811_pHAT.png?raw=true "Title") <p style="text-align:center; font-style:italic;">Raspberry Pi Zero Rough Idle power conspmption </p>

## Other Options

### NRF24

The NRF24L01+ is amazingly cheap on places like AliExpress and seems like a great option. 

To get this going you are going to need to wire this up: 

![Alt text](img/Wireless_Interfaces/nrf24.png?raw=true "Title") <p style="text-align:center; font-style:italic;">Raspberry Pi Zero Rough Idle power conspmption </p>

We also want to enable the SPI interface, by running:

```
sudo raspi-config
```

Then enable the SPI interface.

Install the correct libraries

```
sudo apt-get update
sudo apt-get install python3-pip python3-dev libboost-python-dev libboost-thread-dev git
cd RF24
./configure
make
sudo make install
cd pyRF24
sudo python3 setup.py install
```

If you get an error message about not finding lib_boost. Then:  
  
 ```
 sudo find / -name "libboost_python*.so*"
 ```

Find the name and then create a symbolic link. Create a link from your specific lib boost to something more generic:

```
sudo ln -s /usr/lib/arm-linux-gnueabihf/libboost_python311.so /usr/lib/arm-linux-gnueabihf/libboost_python3.so
```
Then try to install again:
```
sudo python3 setup.py install
```

This is the reciever code:
```
from RF24 import *
from time import sleep

# Setup for Raspberry Pi
radio = RF24(25, 0)  # CE is connected to GPIO 25 (Pin 22), CSN to SPI0 CE0 (Pin 24)

def setup():
    if not radio.begin():
        print("Radio hardware not responding")
        return False
    radio.setPALevel(RF24_PA_MIN)
    radio.setDataRate(RF24_1MBPS)
    radio.setCRCLength(RF24_CRC_16)
    radio.openReadingPipe(1, 0xF0F0F0F0E1)
    radio.startListening()
    print("Radio successfully initialized")
    return True

def receive():
    while True:
        if radio.available():
            while radio.available():
                message = radio.read(32)
            print("Received message: {}".format(message.decode('utf-8')))
        else:
            print("No message received")
        sleep(1)

if __name__ == "__main__":
    if setup():
        radio.printDetails()
        receive()
```

This is the trasmitter code:

```
import spidev
from RF24 import *
from time import sleep

# Setup for Raspberry Pi
radio = RF24(25, 0)  # CE is connected to GPIO 25 (Pin 22), CSN to SPI0 CE0 (Pin 24)

def setup():
    # Set SPI speed using spidev
    spi = spidev.SpiDev()
    spi.open(0, 0)  # Open SPI bus 0, device (CS) 0
    spi.max_speed_hz = 500000  # Set SPI speed to 500 kHz
    spi.close()

    print("Initializing the radio...")
    if not radio.begin():
        print("Radio hardware not responding")
        return False
    radio.setPALevel(RF24_PA_MIN)
    radio.setDataRate(RF24_1MBPS)
    radio.setCRCLength(RF24_CRC_16)
    radio.openWritingPipe(0xF0F0F0F0E1)
    radio.stopListening()
    print("Radio successfully initialized")
    return True

def transmit():
    counter = 0
    while True:
        message = f'Hello {counter}'.encode('utf-8')
        print(f"Sending message: {message.decode('utf-8')}")
        result = radio.write(message)
        if result:
            print("Message sent successfully")
        else:
            print("Message sending failed")
        counter += 1
        sleep(1)

if __name__ == "__main__":
    if setup():
        radio.printDetails()
        transmit()
```

![Alt text](img/Wireless_Interfaces/nrf_load.png?raw=true "Title") <p style="text-align:center; font-style:italic;">NRF24 module transmitting</p>

Overall this module is very cheap and low power. There are however, a few issues. Firstly it uses the 2.4GHz band, which is also used by the WiFi Module so there will potentially be some inteference issues using both at the same time in nearby proximiyt.. Secondly, the trasmission difference is not dissimilar from the onboard WiFi. There is no evidence that we it will be possible to reach the a 1km distance. Finally, on the raspberry Pi, it does not enumerate as a network interface. While it might be possible to create a driver that might create a 6LowPAN style interface on the Pi, the  nRF24L01+ only supports payload sizes up to 32 bytes. To make something that can reach a minimum efficiency requirement, the minimum fram size should be 127 octets. This is what 802.15.4 allows.

## RFM69HCW

This module is currently being tested. 

You need to ensure thta you have enabled SPI in the raspberry pi

```sudo raspi-config```

Got to interface options -> Enable SPI

Here is some sample code to test the RFM69HCW after it has been wired:

You can use the code from this repo: https://github.com/etrombly/RFM69

```
#!/usr/bin/env python3

import RFM69
from RFM69registers import *
import datetime
import time

NODE = 1
OTHERNODE = 2
NET = 1
KEY = "1234567890123456"
TIMEOUT = 5
TOSLEEP = 0.1

radio = RFM69.RFM69(RF69_915MHZ, NODE, NET, True)
print("class initialized")

#print("reading all registers")
#results = radio.readAllRegs()
#for result in results:
#    print(result)

print("Performing rcCalibration")
radio.rcCalibration()

print("setting high power")
radio.setHighPower(True)
#radio.setPowerLevel(0)

print("Checking temperature")
print(radio.readTemperature(0))

print("setting encryption")
radio.encrypt(KEY)

radio.setFrequency(915000000)

radio.writeReg(REG_BITRATEMSB, RF_BITRATEMSB_1200)
radio.writeReg(REG_BITRATELSB, RF_BITRATELSB_1200)

radio.writeReg(REG_FDEVMSB, RF_FDEVMSB_5000)
radio.writeReg(REG_FDEVLSB, RF_FDEVLSB_5000)

print("starting loop...")
sequence = 0
try:
    while True:
        msg = "0000000000111111111122222222223333333333444444444455555555556" ##%d : %d" % (NODE, sequence)
        sequence += 1

        print(f"TX >> {OTHERNODE}: {msg}")
        if radio.sendWithRetry(OTHERNODE, msg, 3, 500):
            print("ACK received")

        print("receiving...")
        radio.receiveBegin()
        timedOut = 0
        while not radio.receiveDone():
            timedOut += TOSLEEP
            time.sleep(TOSLEEP)
            if timedOut > TIMEOUT:
                print("nothing received")
                break

        if timedOut <= TIMEOUT:
            sender = radio.SENDERID
            msg = "".join([chr(letter) for letter in radio.DATA])
            ackReq = radio.ACKRequested()
            print(f"RX << {sender}: {msg} (RSSI: {radio.RSSI})")
            if ackReq:
                print("sending ACK...")
                time.sleep(0.05)
                radio.sendACK()
            time.sleep(TIMEOUT / 2)
except KeyboardInterrupt:
    # Clean up properly to not leave GPIO/SPI in an unusable state
    pass

print("shutting down")
radio.shutdown()

```

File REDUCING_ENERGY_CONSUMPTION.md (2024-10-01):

# Reducing Energy Consumption on the Pi Zero and Pi Zero 2W

The followingy are my observations and notes from testing the Raspberry Pi Zero's power consumption. See below for different methods to reduce power consumption.

Summary
Out of the box, the consumption numbers are:

| **Device** | **State** | **Current (A)** | **Voltage (V)** | **Power (W)** |
|---|---|---|---|---|
| Raspberry Pi Zero W | 0% CPU load | 0.09 | 5.1 | 0.459 |
| Raspberry Pi Zero W | 100% CPU load | 0.16 | 5.1 | 0.816 |
| Raspberry Pi Zero W | Shutdown | 0.0378 | 5.1 | 0.192 |
| Raspberry Pi Zero 2 W | 0% CPU load | 0.12  | 5.1 | 0.612 |
| Raspberry Pi Zero 2 W | 100% CPU load | 0.26 | 5.1 | 1.32 |
| Raspberry Pi Zero 2 W | Shutdown | 0.06 | 5.1 | 0.3 |

## Adding things
Adding the following will increase power consumption:

| **Device/Action** | **State/Action** | **Current Increase (A)** |
|---|---|---|
| Apple 100 Mbit USB2 adaptor | Increase | 0.09 to 0.27 |
| Vantec 1000 Mbit USB3 Gigabit adaptor | Increase | 0.08 to 0.21 |
| RAK2245 LoRaWAN Concentrator | Increase | 0.08 to 0.44 |
| SSH'd in over WiFi on the terminal | Increase | 0.08 to 0.1 |
| Pi Supply LoRa Hat | Idle | Undetectable increase |
| Pi Supply LoRa Hat | Transmitting | 0.08 to 0.1 |

## Reducing Power Consumption

| **Action** | **Current Saving (A)** |
|---|---|
| Disabling HDMI | 0.017 |
| Disabling WiFi | 0.006 |
| Disabling Bluetooth | 0.004 |
| Disabling the On and activity LEDs | 0.002 |

### Disable HDMI
If you don't need the screen, you can save 25mA by disabling HDMI. Put the following in /boot/firmwar/config.txt:
```
dtoverlay=vc4-kms-v3d,nohdmi
max_framebuffers=1
disable_fw_kms_setup=1
disable_overscan=1

enable_tvout=0
```
 
 ### Disable WiFi

To do this, add the following to /boot/config.txt:

```
dtoverlay=disable-wifi
```

Then reboot

### Disable Bluetooth 

To do this, add the following to /boot/config.txt:

```
dtoverlay=disable-bt
```

Disable the Bluetooth and WiFi

### Disable Activity LEDs
To disable the activity LEDs permanently, add the following to /boot/config.txt:

```
dtparam=act_led_trigger=none
dtparam=act_led_activelow=off
```

## Pi Zero 2W Disabling cores

Although Jeff shows that you can decrease peak current by disabling cores, the idle power draw is the same for 1 and 4 cores on the Raspberry Pi. Even when under 100% load the total power consumption between 1 and 4 cores will be very similar because although a single core will have a lower power draw but will draw power for a longer period of time. It's an interesting experiment but I would not reccomend: https://www.jeffgeerling.com/blog/2021/disabling-cores-reduce-pi-zero-2-ws-power-consumption-half

## Sources

  Raspberry Pi
  https://github.com/raspberrypi/documentation/blob/develop/documentation/asciidoc/computers/raspberry-pi/power-supplies.adoc
 
https://kittenlabs.de/blog/2024/09/01/extreme-pi-boot-optimization/ 

Jeff Geerling also does a great job at on this page here: https://www.jeffgeerling.com/blogs/jeff-geerling/raspberry-pi-zero-power.

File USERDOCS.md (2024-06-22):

# User Documentation of the Photon Power Zero

## Before installing the Photon Power Zero on the Pi ###
 
If you have a Raspberry Pi Zero without soldered headers, you are going to need to solder headers on. You can do this yourself and there is a my  [Soldering a header on a Raspberry Pi Zero 2](https://youtu.be/pwCCnsn2Mug) video.
 
Start by writing a headles PiOS lite image onto your SD card. The following video steps you through this, as well as getting the settings right to be able to SSH into your Raspberry Pi without ever plugging a screen in.

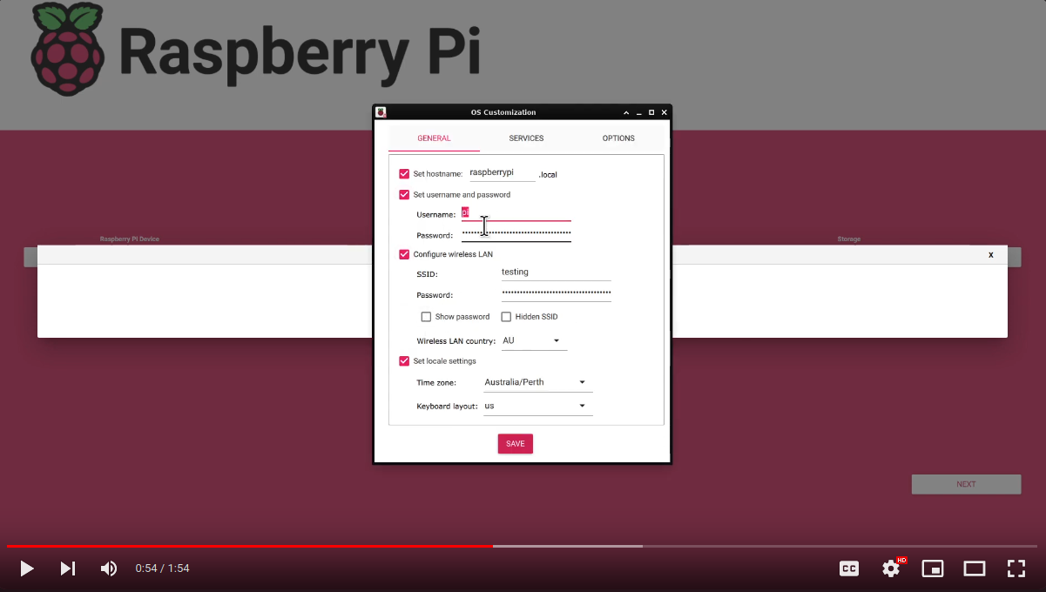
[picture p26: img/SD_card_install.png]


After flashing your Rasberry Pi using the instructions above, insert the SD card into your Raspberry Pi, then power the Raspberry Pi Zero through the micro USB connector as shown in the image below. Note that the first time the Pi Zero boots after flashing the SD card, it takes a while before you can see the device on your LAN. Go get yourself a coffee, be paitent and wait for it to appear; it often takes 5-10 minutes to appear during the first boot of a newly imaged SD card.

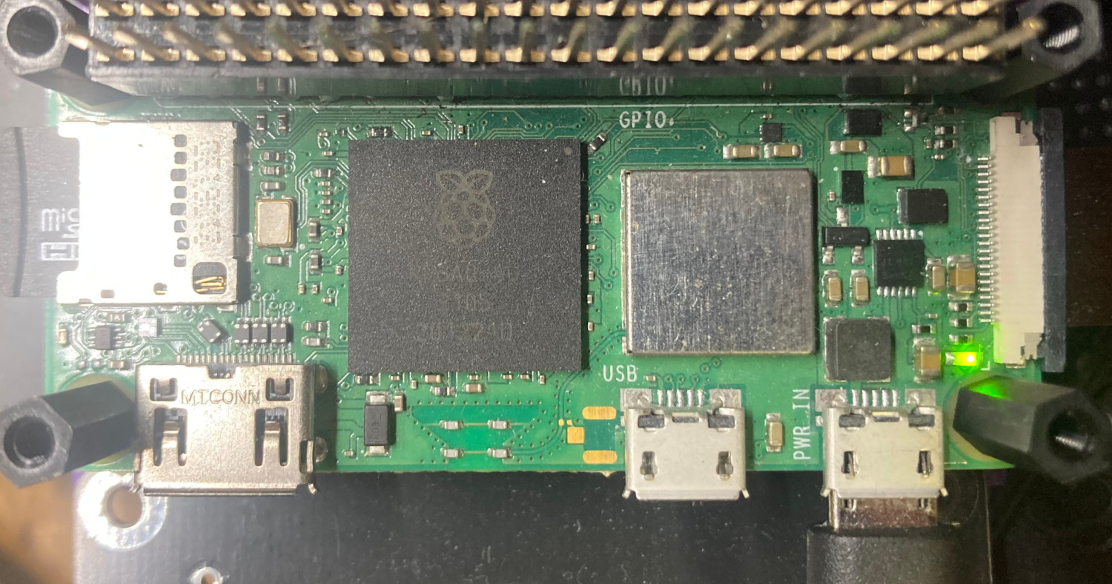
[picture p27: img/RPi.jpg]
<p style="text-align:center; font-style:italic;">Start by Powering the Raspberry Pi through USB

In the image above, the Pi is being powered via a regular USB cable while we set it up for the Photon Power Zero. Make sure you NEVER power it through the Photon Power Zero and the USB port simultaneously. Now:

SSH into your Rasberry Pi with

`ssh [username]@[IP_address_of_Raspberry_Pi]`

Update the package repositories with:

`sudo apt update`

Then run the following three commands to install the required software and libraries:

`sudo apt install python3 tmux libcamera-apps python3-pip`

`sudo apt remove python3-rpi.gpio`

`sudo apt install python3-rpi-lgpio`

Now, we are going to allow a graceful shutdown if GPIO Pin 20 is pulled low; the Raspberry Pi will shut down. This is how a shutdown is initiated from the Photon Power Zero to the Raspberry Pi.

`sudo nano /boot/config.txt`

If you are using the latest 64 bit image you may need to:

`sudo nano /boot/firmware/config.txt`

Then, we insert the following line at the end of the file:

`dtoverlay=gpio-shutdown,gpio_pin=21,active_low=1,gpio_pull=up`

Download the Raspberry Pi code onto your Raspberry Pi. The easiest way to do this is from the command line of your Raspberry Pi you can:

`wget https://raw.githubusercontent.com/DavidMurrayP2P/PhotonPowerZero/main/Code/PPZ_RPi_code.py`

You can then provide the file with execute permissions with

`chmod 777 PPZ_RPi_code.py`

You can then move the file to /usr/bin

`sudo mv PPZ_RPi_code.py /usr/bin/PPZ_RPi_code.py`

Now you can edit:

`sudo nano /etc/rc.local`

Add the following before exit 0

```
sleep 10
su -l pi -c "tmux new -s monitor -d"
su -l pi -c "tmux send-keys -t monitor '/usr/bin/PPZ_RPi_code.py' C-m"
```

Change the username pi to whatever your userlevel user is, save and exit. As an example, I called my raspberry pi user david and therefore my /etc/rc.local file looked similar to below: 

Title<p style="text-align:center; font-style:italic;">The /etc/rc.local file

Now test by running:

`sudo /etc/rc.local`

The command line will appear to hang for 10 seconds before returning you to the terminal. When it does, run:

`tmux attach`

You should have a message saying:

Internet connection working

Note that if you have never used tmux before, you can exit this terminal by hitting 

`ctrl b then d`

Turn off your Pi by removing the USB Power. Now remove the USB cable from your desk; I want to prevent you from powering your Pi through this again. You must NEVER power your Raspberry Pi through that USB port while the Photon Power Zero board is attached.

## Physically Install the Photon Power Zero on the Rasberry Pi Zero

The image below will take you to a YouTube video showing you how to carefully install the Photon Power Zero.

Video Thumbnail

Note: Never power the Raspberry Pi via the LiPo Battery and the USB port on the Raspberry Pi. **You cannot charge the battery from the 5v USB port on the Raspberry Pi.**

Please also ensure that your battery has the correct polarity.
  
Production Kit Title
<p style="text-align:center; font-style:italic;">Make sure the polarity on the JST connector is correct.</p>

Please also ensure that you have read our [LIPO_PURCHASING](LIPO_PURCHASING.md) guide.

Now you can plug in your battery first, then your cable that will charge the battery over USB. If your battery is well charged, your Pi should start booting. Note that if your battery is not well charged and the voltage of your LiPo battery is below 3.75V, then your Raspberry Pi will not turn on. If you are charging from USB, then likely you will need to be very paitent as USB will limit the charge rate to 0.1 Amps.

SSH in and then, as a user, run:

`tmux attach`

You should see the output of the Python program that you have run. You should be seeing your Photon Power Zero reporting a sensible voltage to your Raspberry Pi.

## Troubleshooting ##

If you cannot set up the Wifi and enable SSH from the image creation stage, you can choose to plug in a HDMI connector, connect to your Wifi, and install the open SSH server via the command line with:

```
sudo apt update
sudo apt install openssh-server
```

Note if you are not running the latest version of PiOS, Bookworm or later then you may need to 

```
sudo apt remove python3-rpi.lgpio
sudo apt install python3-rpi-gpio
```

After running this, make sure you reboot.

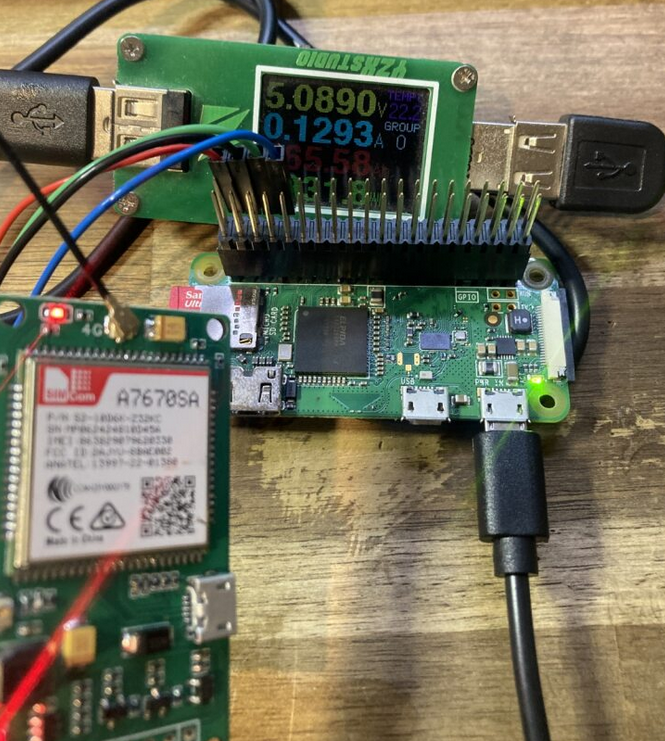
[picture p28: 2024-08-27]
img/Wireless_Interfaces/SIMA7670SA.png

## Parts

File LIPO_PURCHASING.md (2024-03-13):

# LiPo Purchasing considerations

A single cell 3.7V LiPo battery must be sourced and this should be done carefully. I have had success with 4400mAH as a capacity for the Raspberry Pi Zero. 

You must only buy from a trusted supplier such as Adafruit, Core Electronics, Little Bird, Pimoroni. DO NOT buy LiPo from ebay or ali express vendors.
 - https://www.adafruit.com/product/354
 - https://core-electronics.com.au/polymer-lithium-ion-battery-4400mah.html
 - https://shop.pimoroni.com/products/lithium-ion-battery-pack?variant=23417820423
 - https://littlebirdelectronics.com.au/products/lithium-ion-battery-pack-3-7v-4400mah
 - https://www.digikey.com/en/products/detail/adafruit-industries-llc/354/5054541

Many vendors may reverse the polarity of their LiPo Batteries. Do not take any risks or shortcuts here.

The LiPo connector uses a 2 Pin JST connector. It is very important that you get your battery from a reputable supplier and that the polarity on the 2 Pin JST connector is correct.
  
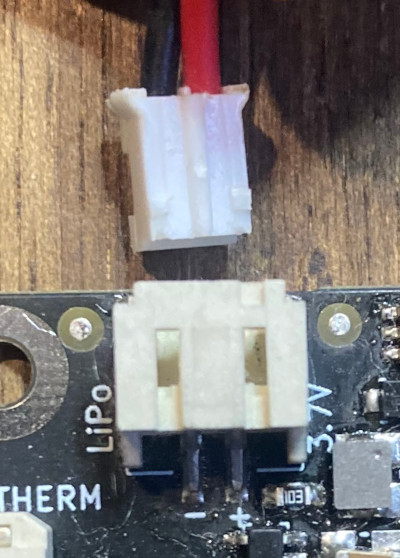
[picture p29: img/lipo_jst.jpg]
Production Kit Title

<p style="text-align:center; font-style:italic;">Make sure the polarity on the JST connector is correct.</p>

This project is not worth doing if you buy cheap batteries, please don't do it.

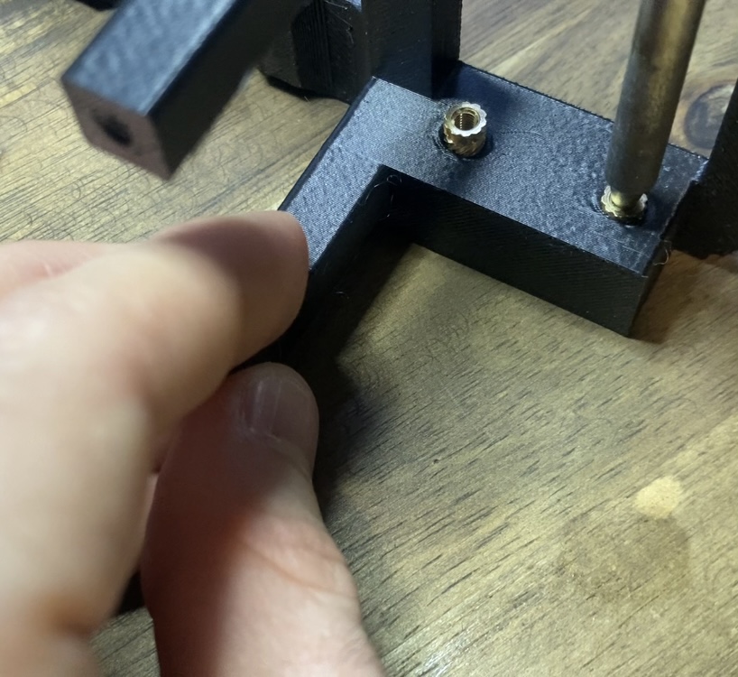
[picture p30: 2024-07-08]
img/hea_set_inserts_two_parts.jpg

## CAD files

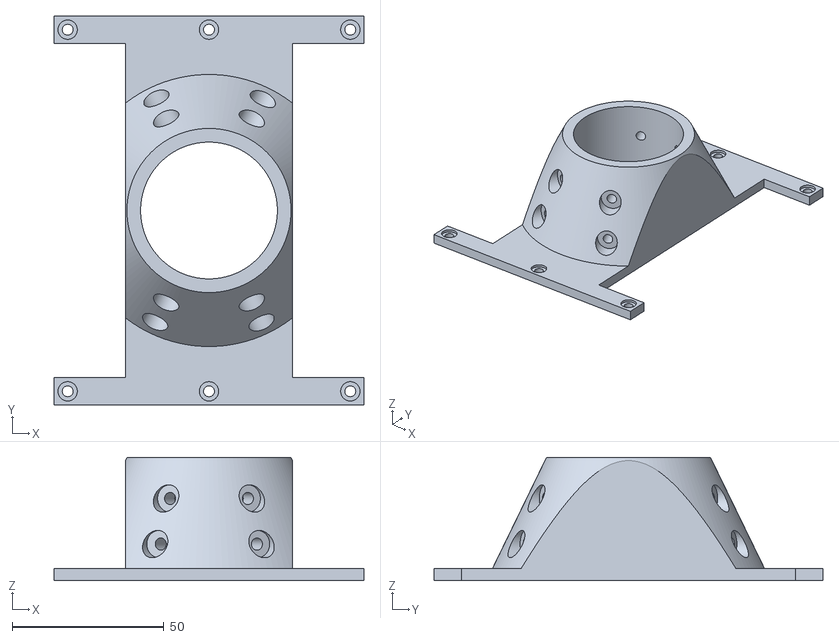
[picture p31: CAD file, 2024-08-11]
FDM/10W_Voltaic_Panel_to_Multicomp_enclosure/pole_mount.stl
102.0 x 128.0 x 40.5

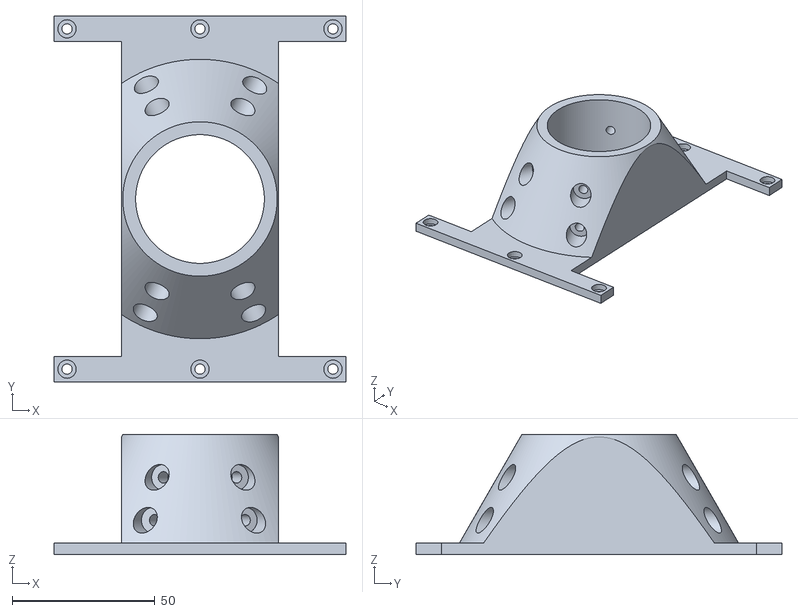
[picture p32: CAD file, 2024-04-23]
FDM/6W_Voltaic_Panel_to_Multicomp_enclosure/Pole_mount.stl
102.0 x 128.0 x 42.0

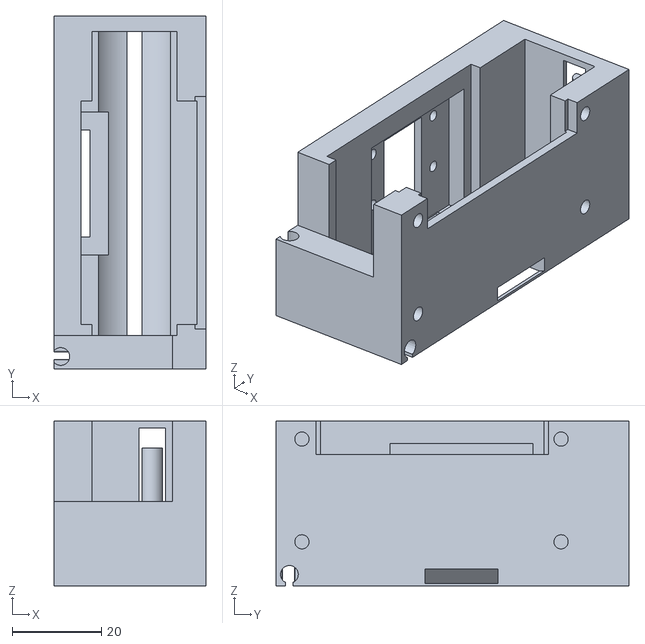
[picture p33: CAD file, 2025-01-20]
FDM/UPS_mount/UPS_mount_r12.stl
34.0 x 79.0 x 36.8

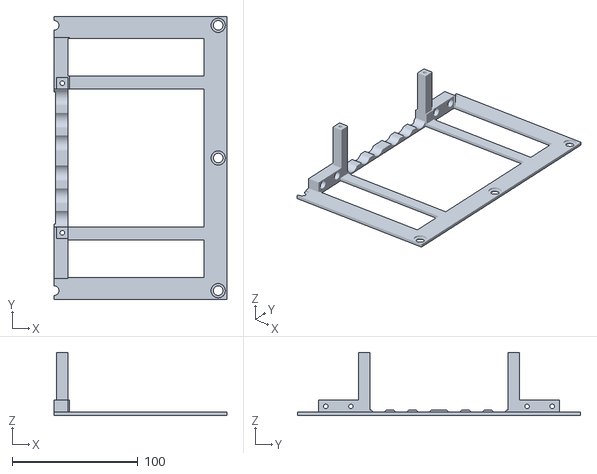
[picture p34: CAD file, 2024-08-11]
FDM/10W_Voltaic_Panel_to_Multicomp_enclosure/Panel_Mount_10W_2nd_half.stl
137.2 x 225.0 x 50.4

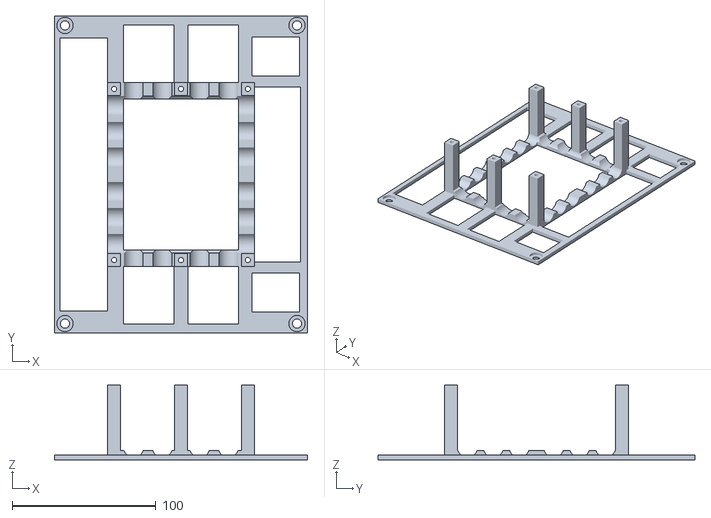
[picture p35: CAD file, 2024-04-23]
FDM/6W_Voltaic_Panel_to_Multicomp_enclosure/Panel_Mount_6W.stl
176.0 x 220.5 x 52.0

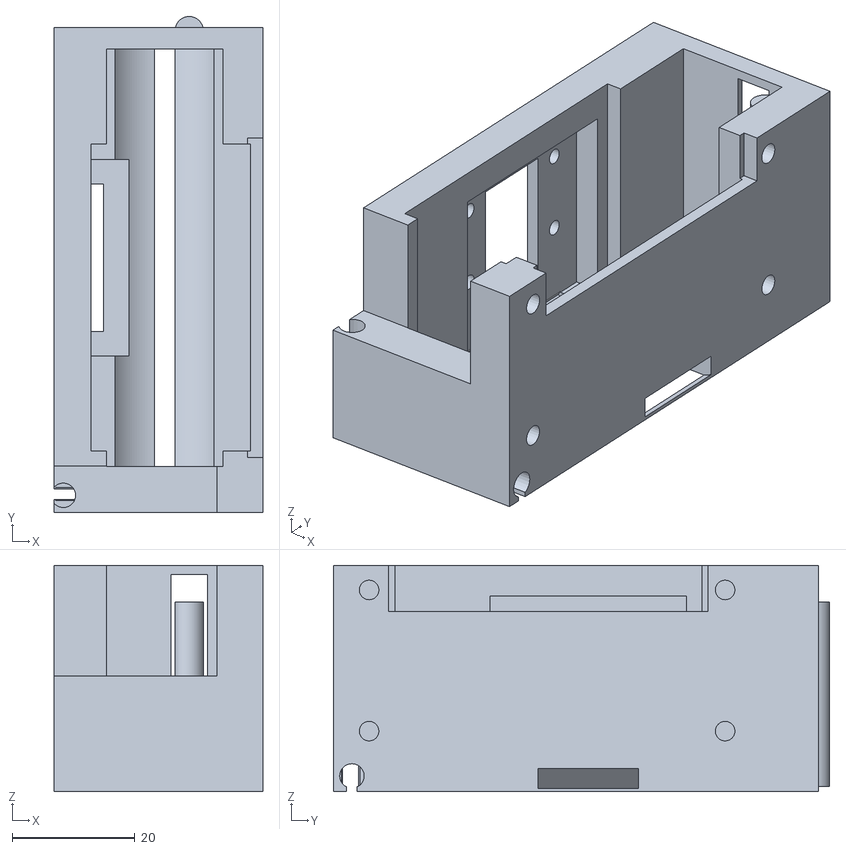
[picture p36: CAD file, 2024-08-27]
FDM/UPS_mount/UPS_mount_r11.stl
34.0 x 80.8 x 36.8

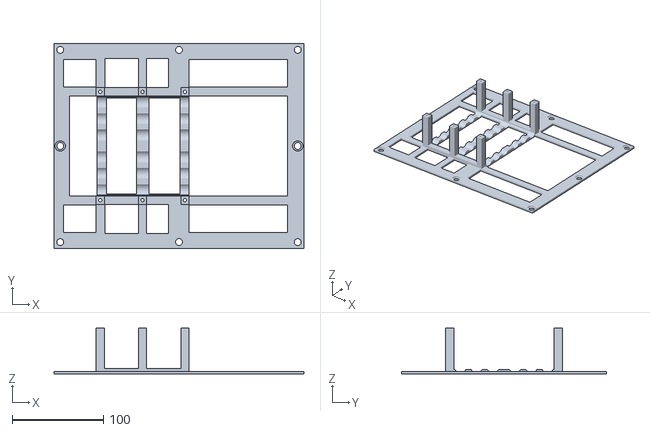
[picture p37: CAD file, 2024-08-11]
FDM/10W_Voltaic_Panel_to_Multicomp_enclosure/Panel_Mount_10W_r2.stl
274.5 x 225.0 x 50.4

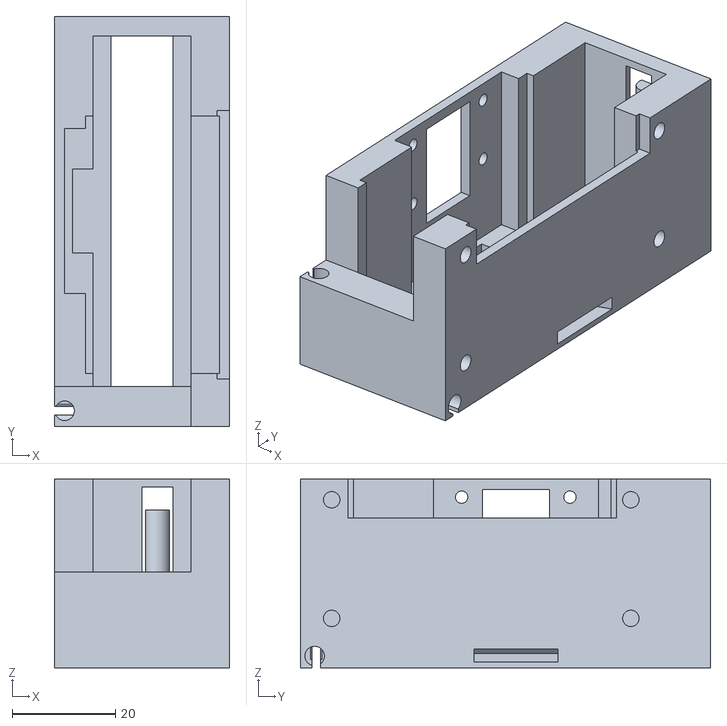
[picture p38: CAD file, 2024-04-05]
FDM/UPS_mount/UPS_mount_r10.stl
34.0 x 79.5 x 36.6

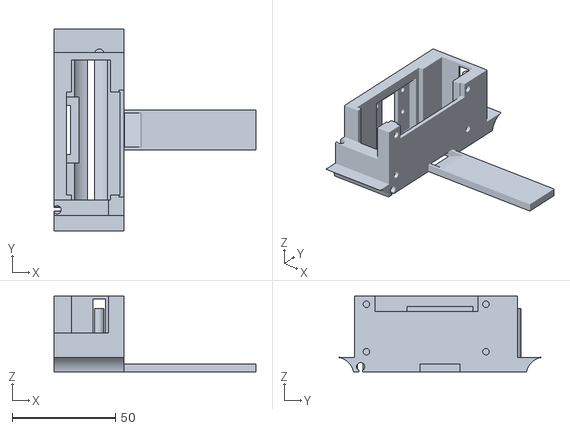
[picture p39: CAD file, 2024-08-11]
FDM/10W_Voltaic_Panel_to_Multicomp_enclosure/case_mount_r10.stl
98.0 x 98.0 x 36.8

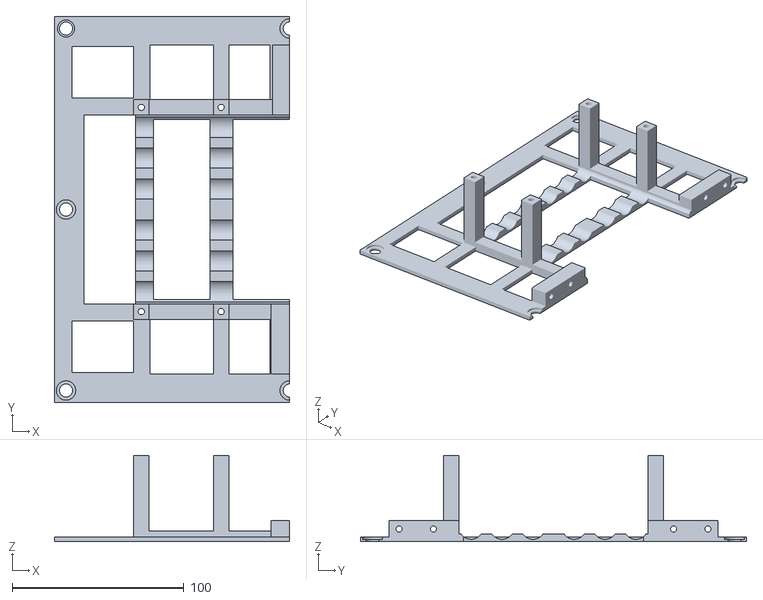
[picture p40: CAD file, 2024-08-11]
FDM/10W_Voltaic_Panel_to_Multicomp_enclosure/Panel_Mount_10W_1st_half.stl
137.2 x 225.0 x 50.4

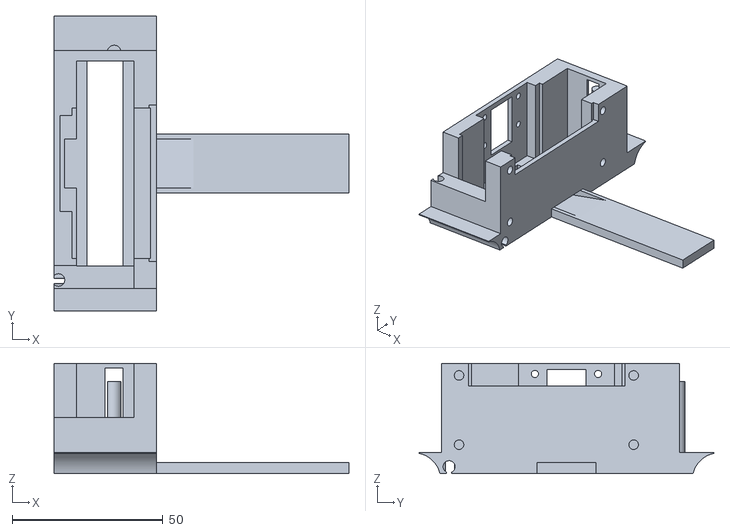
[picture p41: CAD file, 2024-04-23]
FDM/10W_Voltaic_Panel_to_Multicomp_enclosure/Jaycar_case_mount_r10.stl
98.0 x 98.0 x 36.6

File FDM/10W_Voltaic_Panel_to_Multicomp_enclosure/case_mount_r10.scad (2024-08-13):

union () {
difference(){
union(){
translate([-4,0,1.7])cube([98,98,7.1], center=true);    
translate([-13,-2,19.5])cube([80,79,31], center=true); 
translate([-23.5,-6.5,19.5])cube([8,69,31], center=true);
}
    //Cube LiPo Battery Core Electronics style
    translate([-34,-6.5,20])cube([26,50,35], center=true);

    //Dual cylinder lipo Adafruit style
    translate([-35,0,21])cube([19,68,37], center=true);
    translate([-35,0,7.5]) rotate([90,0,0])   cylinder(h=68, r1=9.5, r2=9.5, center=true,$fn=128);
     
    //Outside rail mounts
    translate([0,50.8,-3.6])  rotate([0,90,0])   cylinder(h=115, r1=9, r2=9, center=true,$fn=128);
    translate([0,-50.8,-3.6])  rotate([0,90,0])   cylinder(h=115, r1=9, r2=9, center=true,$fn=128);

    //Hole clearance
    //translate([0,29.5,-17])  rotate([0,90,0])   cylinder(h=115, r1=17, r2=17, center=true,$fn=128);
    //translate([0,-29.5,-17])  rotate([0,90,0])   cylinder(h=115, r1=17, r2=17, center=true,$fn=128);
    
    //Cavity for camera cable
    translate([-46.6,0,-1.2]) rotate([0,-60,0]) cube([3.7,24,9], center=true);
    translate([-21,0,-0.5]) rotate([0,-22,0]) cube([30,16.3,3], center=true);

    //Camera cable routing
    translate([-31,38,20])  rotate([0,0,0])   cylinder(27, r1=5, r2=5, center=true,$fn=128);
    
    ///camera holes
    translate([-51,10.5,24.5])rotate([0,90,0])   cylinder(h=5, r1=1.2, r2=1.2, center=true,$fn=24);
    translate([-51,-10.5,24.5])rotate([0,90,0])   cylinder(h=5, r1=1.2, r2=1.2, center=true,$fn=24);
    translate([-51,10.5,12])rotate([0,90,0])   cylinder(h=5, r1=1.2, r2=1.2, center=true,$fn=24);
    translate([-51,-10.5,12])rotate([0,90,0])   cylinder(h=5, r1=1.2, r2=1.2, center=true,$fn=24);

    //camera cutout
    translate([-52,0,16])cube([8,13,20], center=true);
    
    //Camera installation
    translate([-41,0,15])cube([20,32,30], center=true);
    
    //Holes for battery terminals and solar plug
    translate([30,-30,16])cube([98,40.5,40], center=true);
    translate([30,30,16])cube([98,40.5,40], center=true);
    
     //battery cable routing
    translate([-34,-37,27])  cube([15,10,20], center=true);
    translate([-51.5,-38.7,9]) rotate([0,0,0])  cylinder(h=20, r1=2, r2=2, center=true,$fn=24);
    translate([-36,-38.5,0])  cube([35,1.7,5], center=true);

    translate([-46,-39.5,29])  cube([20,11.1,24], center=true);
   
    translate([-35.3,-38.5,0.7])rotate([0,90,0])   cylinder(h=35, r1=2, r2=2, center=true,$fn=24);

    
    
     //Pi Zero holes  
    translate([-17,-35.7,31])rotate([0,90,0])   cylinder(h=17.5, r1=1.6, r2=1.6, center=true,$fn=24);
    translate([-17,22.3,31])rotate([0,90,0])   cylinder(h=17.5, r1=1.6, r2=1.6, center=true,$fn=24);
    translate([-17,-35.7,8])rotate([0,90,0])   cylinder(h=17.5, r1=1.6, r2=1.6, center=true,$fn=24);
    translate([-17,22.3,8])rotate([0,90,0])   cylinder(h=17.5, r1=1.6, r2=1.6, center=true,$fn=24);
    
    
    //Pi 4 cutout 85.6mm × 56.5mm
    //translate([52,0.8,25])cube([58,87,30], center=true);
    //Pi Zero cut out 65mm x 30mm
    //translate([6,-9,22])cube([42,120,33], center=true);
    
    //Pi PCB cutout
    translate([16,-6.5,20])cube([70,70.5,36], center=true);
    translate([7,-6.5,35])cube([57,52,15], center=true);

    //Ventilation
    
    //#translate([-44,0,20])rotate([90,0,0])   cylinder(h=60, r1=2, r2=2, center=true,$fn=24);
    //translate([-30,0,20])rotate([90,0,0])   cylinder(h=88, r1=2, r2=2, center=true,$fn=24);    
    //translate([-44,-6.5,10])rotate([90,0,0])   cylinder(h=88, r1=2, r2=2, center=true,$fn=24);
    //translate([-30,0,10])rotate([90,0,0])   cylinder(h=88, r1=2, r2=2, center=true,$fn=24);    
    //#translate([-44,0,30])rotate([90,0,0])   cylinder(h=60, r1=2, r2=2, center=true,$fn=24);
    //translate([-30,0,30])rotate([90,0,0])   cylinder(h=88, r1=2, r2=2, center=true,$fn=24);    

}
//Camera cable routing
translate([-31,37,14])  rotate([0,0,0])   cylinder(30, r1=2.3, r2=2.3, center=true,$fn=128);
        }

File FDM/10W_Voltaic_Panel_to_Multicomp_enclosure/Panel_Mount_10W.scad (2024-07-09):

//Mount to the solar pannel

//Notes: This is the total object but is printed in multiple parts.

difference(){
union(){
    translate([0,0,2])cube([274.5,225,3.5],center=true,$fn=24);
    translate([-10,0,3.8])cube([102,128,6],center=true,$fn=24);
    
    translate([36.5, -59.5, 26])cube([9,9,48], center=true,$fn=24);
    translate([-56.5, -59.5, 26])cube([9,9,48], center=true,$fn=24);
    translate([36.5, 59.5, 26])cube([9,9,49], center=true,$fn=24);
    translate([-56.5, 59.5, 26])cube([9,9,48], center=true,$fn=24);
    translate([-10,59.5, 26])cube([9,9,48], center=true,$fn=24);
    translate([-10, -59.5, 26])cube([9,9,48], center=true,$fn=24);
    
    //You can comment the 4 lines below if you print in one piece
    translate([-2,75.5, 10])cube([25,41,15], center=true,$fn=128);
    translate([-2, -75.5, 10])cube([25,41,15], center=true,$fn=128);
   
}
    //Uncomment these to half the plate
    //translate([100,0,0])cube([200,250,110],center=true,$fn=24);
    //translate([-100,0,0])cube([200,250,110],center=true,$fn=24);

    //Screws for the two parts to put together
    translate([0, -70, 10])rotate([0,90,0])cylinder(h=40, r=1.8, center=true,$fn=24);
    translate([11, -70, 10])rotate([0,90,0])cylinder(h=10, r=3.5, center=true,$fn=24);
    translate([-15, -70, 10])rotate([0,90,0])cylinder(h=6, r=2.25, center=true,$fn=24);

    translate([0, -90, 10])rotate([0,90,0])cylinder(h=40, r=1.8, center=true,$fn=24);
    translate([11, -90, 10])rotate([0,90,0])cylinder(h=10, r=3.5, center=true,$fn=24);
    translate([-15, -90, 10])rotate([0,90,0])cylinder(h=6, r=2.25, center=true,$fn=24);

    translate([0, 70, 10])rotate([0,90,0])cylinder(h=40, r=1.8, center=true,$fn=24);
    translate([11, 70, 10])rotate([0,90,0])cylinder(h=10, r=3.5, center=true,$fn=24);
    translate([-15, 70, 10])rotate([0,90,0])cylinder(h=6, r=2.25, center=true,$fn=24);

    translate([0, 90, 10])rotate([0,90,0])cylinder(h=40, r=1.8, center=true,$fn=24);
    translate([11, 90, 10])rotate([0,90,0])cylinder(h=10, r=3.5, center=true,$fn=24);
    translate([-15, 90, 10])rotate([0,90,0])cylinder(h=6, r=2.25, center=true,$fn=24);
    

    //subtracting from the bottom plate    
    translate([-10,0,27.3])cube([104,110,45],center=true,$fn=24);

    translate([-35,0,2])cube([30,105,100],center=true,$fn=24);
    translate([15,0,2])cube([30,105,100],center=true,$fn=24);

    translate([-92,80,2])cube([62,30,100],center=true,$fn=24);
    translate([-92,-80,2])cube([62,30,100],center=true,$fn=24);
    translate([82,0,2])cube([82,110,100],center=true,$fn=24);

    translate([82,80,2])cube([82,30,100],center=true,$fn=24);
    translate([82,-80,2])cube([82,30,100],center=true,$fn=24);
    translate([-92,0,2])cube([62,110,100],center=true,$fn=24);

    translate([21,80,2])cube([21,32,200],center=true,$fn=24);
    translate([-33,-80,2])cube([37,32,100],center=true,$fn=24);
    translate([-33,80,2])cube([37,32,100],center=true,$fn=24);
    translate([21,-80,2])cube([21,32,200],center=true,$fn=24);
    
    //Cutouts for pannel screws
    translate([-130.4,-105.5, 1])cylinder(h=5, r=3.8, center=true,$fn=24);
    translate([-130.4, 105.5 , 1])cylinder(h=5, r=3.8, center=true,$fn=24);
    translate([-130.4,-105.5, 4])cylinder(h=4, r=5.7, center=true,$fn=24);
    translate([-130.4,105.5, 4])cylinder(h=4, r=5., center=true,$fn=24);

    translate([0,-105.5, 1])cylinder(h=5, r=3.8, center=true,$fn=24);
    translate([0, 105.5 , 1])cylinder(h=5, r=3.8, center=true,$fn=24);
    translate([0,-105.5, 4])cylinder(h=4, r=5.7, center=true,$fn=24);
    translate([0,105.5, 4])cylinder(h=4, r=5.7, center=true,$fn=24);
    
    translate([130.4,0, 1])cylinder(h=5, r=3.8, center=true,$fn=24);
    translate([-130.4, 0 , 1])cylinder(h=5, r=3.8, center=true,$fn=24);
    translate([130.4,0, 4])cylinder(h=4, r=5.7, center=true,$fn=24);
    translate([-130.4,0, 4])cylinder(h=4, r=5.7, center=true,$fn=24);
    
    translate([130.4,-105.5, 1])cylinder(h=5, r=3.8, center=true,$fn=24);
    translate([130.4,105.5, 1])cylinder(h=5, r=3.8, center=true,$fn=24);
    translate([130.4,-105.5, 4])cylinder(h=4, r=5.7, center=true,$fn=24);
    translate([130.4,105.5, 4])cylinder(h=4, r=5.7, center=true,$fn=24);
    
    //Heat set inserts
    translate([36.5, 59.5, 0])cylinder(h=8, r=2.3, center=true,$fn=24);
    translate([-56.5, -59.5, 0])cylinder(h=8, r=2.3, center=true,$fn=24);
    translate([-56.5, 59.5,0])cylinder(h=8, r=2.3, center=true,$fn=24);
    translate([36.5, -59.5, 0])cylinder(h=8, r=2.3, center=true,$fn=24);
    translate([-10, 59.5,0])cylinder(h=8, r=2.3, center=true,$fn=24);
    translate([-10, -59.5, 0])cylinder(h=8, r=2.3, center=true,$fn=24);

    translate([36.5, 59.5, 15])cylinder(h=100, r=1.85, center=true,$fn=24);
    translate([-56.5, 59.5, 15])cylinder(h=100, r=1.85, center=true,$fn=24);
    translate([36.5, -59.5, 15])cylinder(h=100, r=1.85, center=true,$fn=24);
    translate([-56.5, -59.5, 15])cylinder(h=100, r=1.85, center=true,$fn=24);
    translate([-10, -59.5, 15])cylinder(h=100, r=1.85, center=true,$fn=24);
    translate([-10, 59.5, 15])cylinder(h=100, r=1.85, center=true,$fn=24);
    
    //Air flow
    translate([-43,0,9])  rotate([90,0,0])   cylinder(h=100, r=7, center=true,$fn=128);
    translate([23,0,9])  rotate([90,0,0])   cylinder(h=100, r=7, center=true,$fn=128);
    
    translate([-23,0,9])  rotate([90,0,0])   cylinder(h=100, r=7, center=true,$fn=128);
    translate([3,0,9])  rotate([90,0,0])   cylinder(h=100, r=7, center=true,$fn=128);
    
    translate([0,48,9])  rotate([0,90,0])   cylinder(h=140, r=7, center=true,$fn=128);
    translate([0,-48,9])  rotate([0,90,0])   cylinder(h=140, r=7, center=true,$fn=128);
    
    translate([0,12,9])  rotate([0,90,0])   cylinder(h=140, r=7, center=true,$fn=128);
    translate([0,-12,9])  rotate([0,90,0])   cylinder(h=140, r=7, center=true,$fn=128);
    
    translate([0,30,9])  rotate([0,90,0])   cylinder(h=140, r=7, center=true,$fn=128);
    translate([0,-30 ,9])  rotate([0,90,0])   cylinder(h=140, r=7, center=true,$fn=128);
}

//Pole mount
translate([-10,0,52])difference(){ 


difference(){
union(){
cube([102,128,4],center=true);
translate([0,0,20])cylinder(h=37, r1=45, r2=27, center=true,$fn=128);
}
    translate([46.5, 59.5, -25])cylinder(h=100, r=1.8, center=true,$fn=24);
    translate([-46.5, -59.5, -25])cylinder(h=100, r=1.8, center=true,$fn=24);
    translate([-46.5, 59.5, -25])cylinder(h=100, r=1.8, center=true,$fn=24);
    translate([46.5, -59.5, -25])cylinder(h=100, r=1.8, center=true,$fn=24);
    translate([0, 59.5, -25])cylinder(h=100, r=1.8, center=true,$fn=24);
    translate([0, -59.5, -25])cylinder(h=100, r=1.8, center=true,$fn=24);
   
    translate([46.5, 59.5, 2])cylinder(h=2, r=3.2, center=true,$fn=24);
    translate([-46.5, -59.5, 2])cylinder(h=2, r=3.2, center=true,$fn=24);
    translate([-46.5, 59.5,2])cylinder(h=2, r=3.2, center=true,$fn=24);
    translate([46.5, -59.5, 2])cylinder(h=2, r=3.2, center=true,$fn=24);
    translate([0, 59.5,2])cylinder(h=2, r=3.2, center=true,$fn=24);
    translate([0, -59.5, 2])cylinder(h=2, r=3.2, center=true,$fn=24);

    //pole mount holes
    translate([0,0,25])cylinder(h=60, r=22.5, center=true,$fn=128); //Adjust this for different pole sizes
    

    translate([0,0,25])rotate([90,0,25])   cylinder(h=100, r1=2, r2=2, center=true,$fn=124);
    translate([0,0,10])rotate([90,0,-25])   cylinder(h=100, r1=2, r2=2, center=true,$fn=124);
    translate([0,0,10])rotate([0,90,115])   cylinder(h=100, r1=2, r2=2, center=true,$fn=124);
    translate([0,0,25])rotate([0,90,-115])   cylinder(h=100, r1=2, r2=2, center=true,$fn=124);
    
    translate([0,0,25])rotate([90,0,25])   cylinder(h=100, r1=2, r2=2, center=true,$fn=124);
    translate([0,0,10])rotate([90,0,-25])   cylinder(h=100, r1=2, r2=2, center=true,$fn=124);
    translate([0,0,10])rotate([0,90,115])   cylinder(h=100, r1=2, r2=2, center=true,$fn=124);
    translate([0,0,25])rotate([0,90,-115])   cylinder(h=100, r1=2, r2=2, center=true,$fn=124);

    translate([14.5,-31,25])rotate([90,0,25])   cylinder(h=7.9, r=4.5, center=true,$fn=124);
    translate([-18.5,-38.3,10])rotate([90,0,-25])   cylinder(h=10, r=4.5, center=true,$fn=124);
    translate([18,-38.3,10])rotate([0,90,115])   cylinder(h=10, r=4.5, center=true,$fn=124);
    translate([-14.5,-31,25])rotate([0,90,-115])   cylinder(h=7.9, r=4.5, center=true,$fn=124);
    
    translate([-14.5,31,25])rotate([90,0,25])   cylinder(h=7.9, r=4.5, center=true,$fn=124);
    translate([18.5,38.3,10])rotate([90,0,-25])   cylinder(h=10, r=4.5, center=true,$fn=124);
    translate([-18,38.3,10])rotate([0,90,115])   cylinder(h=10, r=4.5, center=true,$fn=124);
    translate([14.5,31,25])rotate([0,90,-115])   cylinder(h=7.9, r=4.5, center=true,$fn=124);

    
    translate([-60, 0, 10])cube([65,110,70],center=true);
    translate([60, 0, 10])cube([65,110,70],center=true);
         

}
}

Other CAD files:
FDM/10W_Voltaic_Panel_to_Multicomp_enclosure/case_mount_r9.scad
FDM/10W_Voltaic_Panel_to_Multicomp_enclosure/Panel_Mount_10W_r2.scad
FDM/6W_Voltaic_Panel_to_Multicomp_enclosure/Panel_Mount_6W.scad
FDM/UPS_mount/UPS_mount_r10.scad
FDM/UPS_mount/UPS_mount_r11.scad
FDM/UPS_mount/UPS_mount_r12.scad

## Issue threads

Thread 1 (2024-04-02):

ideal for mesh

bialystok, 2024-04-02:
Ideal solution for mesh network wifi. But guestion is how setup host?
How turn off-on network if power is to small. Meybe run host only few hours in day and few in night when the power is too small for working whole day.

DavidMurrayP2P, 2024-04-03:
This is a use case that I am yet to try, but it is interesting.

Yes so the board will currently gracefully shutdown the RPi when the LiPo battery voltage drops below 3.45V and switch it back on when the voltage has increased again past 3.75V. The size of the panel usually need to be massively over speced to have continuous 24x7 operation. Likely, as the battery depletes overnight the voltage will drop, the Pi will shutdown, and then resume the next morning after a couple of sunny hours.

bialystok, 2024-04-03:
But communications we need to synchronize in some way? Let's say we send messages at twelve o'clock at night. And we want to get a reply, but we only have electricity during the day.

If there are more nodes we need to arrange when we transmit so that several nodes have electricity at the same time so that we don't transmit when another node is sleeping. And if we make to talk always at the same time there will be no bandwidth.

The second issue is the replaceable battery. I would prefer it to be 18650, for example, in a 2 piece or three piece version. But charged separately. Discharged separately. And that I could in an emergency situation use any capacity of them. e.g. each different and one empty because I just took to the flashlight.

DavidMurrayP2P, 2024-04-04:
Thanks for the feedback. You can certainly use a larger battery and a larger solar panel. Perhaps the Pi Zero will get more efficient with time which will reduce the cost, in terms of solar size and battery size to build a 24x7 mesh node. This may be possible right now with the right conditions, but it is not yet something that I have tested, and testing in Australia may yield different results from winter in Norway.

bialystok, 2024-04-04:
That's why he doesn't write about it always being 24/7. The idea is that the overlay should allow for different boot scenarios. Depending on the time but also on the capacity/amount of current power.

Electricity can always be in short supply. Even because there is a blockout. But we want to ensure that the network works when the amount of resources is not ideal

Closed 2024-04-04.

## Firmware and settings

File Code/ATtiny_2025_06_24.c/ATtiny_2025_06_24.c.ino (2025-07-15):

#include <avr/io.h>
#include <avr/interrupt.h>
#include <util/delay.h>
#include <avr/sleep.h>
#include <avr/wdt.h>


#define ADC_BATT_INPUT PB0    // Pin for the ADC input

#define PWR             PA7    // Pin for the LED
#define ACTIVE          PA6    // Pin for the LED
#define AP2161          PB0    // Pin when set low will trigger the Pi on
#define SHUTDOWN_PIN    PB2    // Trigger this pin to enable the Pi to gracefully shutdown

#define ALIVE_PIN_1     PA2
#define ALIVE_PIN_2     PA4

#define SHUTDOWN_PIN    PB2    // Trigger this pin to enable the Pi to gracefully shutdown

#define START_PIN       PA1
#define CLOCK_PIN       PA3
#define DATA_PIN        PA5

// Global variable using extern
uint8_t CLOCK_PIN_STATE;

void initADC()
{

   ADMUX =
            (0 << REFS1) |     // Sets ref. voltage to Vcc, bit 1   
            (0 << REFS0) |     // Sets ref. voltage to Vcc, bit 0
            (0 << MUX5)  |     // use ADC1 for input (PA1), MUX bit 5
            (0 << MUX4)  |     // use ADC1 for input (PA1), MUX bit 4
            (0 << MUX3)  |     // use ADC1 for input (PA1), MUX bit 3
            (0 << MUX2)  |     // use ADC1 for input (PA1), MUX bit 2
            (0 << MUX1)  |     // use ADC1 for input (PA1), MUX bit 1
            (0 << MUX0);       // use ADC1 for input (PA1), MUX bit 0

  ADCSRA = 
            (1 << ADEN)  |     // Enable ADC 
            (1 << ADPS2) |     // set prescaler to 16, bit 2 
            (0 << ADPS1) |     // set prescaler to 16, bit 1 
            (0 << ADPS0);      // set prescaler to 16, bit 0 
      
  ADCSRB = 
  //        (1 << ADLAR);      // left shift result (for 8-bit values)
            (0 << ADLAR);      // right shift result (for 10-bit values)
}

void Blink_LEDs() {
  for (int i=0;i<20;i++) {
    PORTA |= (1 << PWR);
    PORTA |= (1 << ACTIVE);
    _delay_ms(250);
    PORTA &= ~(1 << ACTIVE);
    PORTA &= ~(1 << PWR);        
    _delay_ms(250);
    }
}

bool start_pin_high() {
    if (PINA & (1 << START_PIN )) { //Has it been pulled high?
        return true;  // PA2 is high
        }
    else {
        return false; // PA2 is low
        }
    }
    
bool has_CLOCK_PIN_Changed() {
    // Read the current status of CLOCK_PIN
    uint8_t currentPinStatus = PINA & (1 << CLOCK_PIN);
  
    // Check if the pin status has changed from high to low or low to high
    if (currentPinStatus != CLOCK_PIN_STATE) {
        CLOCK_PIN_STATE = currentPinStatus;
        return true; // Pin status has changed
        } 
    else {
        return false; // Pin status is the same
        }
    }

void turn_on_pi() {
    PORTB &= ~(1 << AP2161);
    PORTA |= (1 << PWR);
    _delay_ms(100000); //100 seconds
    }

bool is_Pi_Power_On() {
    // Check if PA7 is set high and PB0 is set low
    if ((PINA & (1 << PWR)) && !(PINB & (1 << AP2161))) {
        return true;  // Conditions are met
        }
    else {
        return false; // Conditions are not met
        }
    }
   
bool is_Pi_Booted() {
    if (PINA & (1 << ALIVE_PIN_1 )) { //Has it been pulled high?
        return true;  // PA2 is high
        }
    else {
        return false; // PA2 is low
        }
    }

bool has_Pi_ever_entered_expert_mode() {
    if (PINA & (1 << ALIVE_PIN_1 )) { //Has it been pulled high?
        return true;  // PA2 is high
        }
    }

bool is_Pi_ready_for_data() {
    if (PINA & (1 << ALIVE_PIN_2 )) { //Has it been pulled high?
        return true; //PA4 is high
        }
    else {
        return false; //PA4 is low
        }
      
    }

void graceful_shutdown() {
    PORTB |= (1 << SHUTDOWN_PIN); // set high
    PORTA |= (1 << PWR);
    _delay_ms(500); 
    PORTB &= ~(1 << SHUTDOWN_PIN); // set low
    PORTA &= ~(1 << PWR);
    _delay_ms(500);
    PORTB |= (1 << SHUTDOWN_PIN); // set high
    PORTA |= (1 << PWR);
    _delay_ms(500); 
    PORTB &= ~(1 << SHUTDOWN_PIN); // set low
    PORTA &= ~(1 << PWR);
    _delay_ms(500);
    PORTB |= (1 << SHUTDOWN_PIN); // set high
    PORTA |= (1 << PWR);
    _delay_ms(500); 
    _delay_ms(10000);
    }


void turn_off_pi() {
    PORTB |= (1 << AP2161); // set high to switch off
    PORTA &= ~(1 << PWR); // set the LED to low
    PORTA &= ~(1 << ACTIVE); //set the state low
    // Calculate the number of sleep cycles for 1 hour (3600 seconds)
    for (int i=2; i>0; i--) { // So sleep for 2 hours
        _delay_ms(3500000); // 1 hour
        }
    }

void set_pins() {
    initADC();
    //Note DDRA or DDRB sets the pin status as an output and |= sets the default status as high
    DDRA |= (1 << PWR); //Set as an ouput Pin
    PORTA &= ~(1 << PWR); //set the state low
    DDRA |= (1 << ACTIVE);
    PORTA &= ~(1 << ACTIVE); //set the state low
    DDRB |= (1 << AP2161);
    PORTB |= (1 << AP2161); //set the state high
    DDRB |= (1 << SHUTDOWN_PIN);
    PORTB &= ~(1 << SHUTDOWN_PIN); //set the state low

    DDRA |= (1 << DATA_PIN); //Set as an ouput Pin
    DDRA |= (1 << CLOCK_PIN); //Set as an ouput Pin
    DDRA |= (1 << START_PIN); //Set as an ouput Pin
    

    DDRA &= ~(1 << ALIVE_PIN_1); //Set as an input Pin
    PORTA &= ~(1 << ALIVE_PIN_1); //Disable the internal pull-up resistor
    DDRA &= ~(1 << ALIVE_PIN_2); //Set as an input Pin
    PORTA &= ~(1 << ALIVE_PIN_2); //Disable the internal pull-up resistor
    

    CLOCK_PIN_STATE = (PINB & (1 << CLOCK_PIN)) >> CLOCK_PIN;
}

int get_voltage_from_adc() {
    uint16_t battery_voltage;
    ADCSRA |= (1 << ADSC);         // start ADC measurement
    
    while (ADCSRA & (1 << ADSC)); // wait till conversion complete 

    // Read ADC value
    uint16_t adcValue = ADC;

    // Apply suggested changes for better accuracy
    
    uint16_t sum = 0;
    uint8_t numReadings = 5; // Number of readings to average
    
    for (uint8_t i = 0; i < numReadings; i++) {
        ADCSRA |= (1 << ADSC);         // start ADC measurement
        while (ADCSRA & (1 << ADSC)); // wait till conversion complete 
        sum += ADC;
        }
        
    uint16_t average = sum / numReadings;

    // Scaling factor to scale 1024 into a no decimal place voltage and account for the voltage divider
    battery_voltage = average *0.586;
    return(battery_voltage); 
}

// Function to transmit a single bit to Raspberry Pi
void transmitBit(uint8_t bit) {
    // Set DATA_PIN according to the bit value
    if (bit) {
        PORTA |= (1 << DATA_PIN);
    } else {
        PORTA &= ~(1 << DATA_PIN);
    }
    
    // Toggle CLOCK_PIN to transmit the bit
    PORTA |= (1 << CLOCK_PIN);
    _delay_ms(50);
    PORTA &= ~(1 << CLOCK_PIN);
    _delay_ms(50);
}

// Function to transmit a 8-bit value to Raspberry Pi
void BitBang(uint8_t value) {
    // Transmit each bit (MSB first)
    // Toggle START_PIN to transmit the bytes
    PORTA |= (1 << CLOCK_PIN);
    _delay_ms(50);
    PORTA |= (1 << START_PIN);
    _delay_ms(50);
    PORTA &= ~(1 << START_PIN);
    _delay_ms(50);

    
    for (uint8_t i = 8; i > 0; i--) {
        uint8_t bit = (value >> i) & 0x01;
        transmitBit(bit);
    }
}

uint8_t fit_8_bits(uint16_t battery_voltage) {
        
    // Ensure the result value fits into a uint8_t
    uint8_t result;
    if (battery_voltage > UINT8_MAX) {
        result = UINT8_MAX;  // If overflow, set to the maximum value of uint8_t
    } else {
        result = (uint8_t)battery_voltage;
    }

    return result;
}

int main( void ) {

  set_pins();  
  uint16_t battery_voltage;
  uint8_t shifted_voltage;
  Blink_LEDs();
  bool expert_mode = false;
  
  while(1) {

    battery_voltage = get_voltage_from_adc();
    if (is_Pi_Power_On()) {
        expert_mode = has_Pi_ever_entered_expert_mode();
        if (expert_mode == true) {
            if (is_Pi_Booted()) {
                if (is_Pi_ready_for_data()) {
                    PORTA |= (1 << ACTIVE);
                    shifted_voltage = fit_8_bits(battery_voltage);
                    BitBang(shifted_voltage);
                    _delay_ms(100);
                    }
                else {
                    PORTA &= ~(1 << ACTIVE); // set the LED to low
                    }
                }
             else {
                graceful_shutdown();
                turn_off_pi(); 
                Blink_LEDs();
                }
            
            }
            else { 
                // We are not in expert mode
                }
        }
    else { // The Pi must be off
        if ((battery_voltage*2) > 375) {
            turn_on_pi();
            }
        else if ((battery_voltage*2) < 345) {
            graceful_shutdown();
            turn_off_pi();    
            } 
        else {
            //Do nothing
            }
        }
    }
}

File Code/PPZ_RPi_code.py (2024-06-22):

#!/usr/bin/python3

import RPi.GPIO as GPIO
import os
import datetime
import sys
import time
import subprocess

# Configure the GPIO pins for data transfer
ALIVE_PIN1 = 16
ALIVE_PIN2 = 20

START_PIN = 13
CLOCK_PIN = 19
DATA_PIN = 26

shutdown_start_hour = 18
shutdown_end_hour = 6

GPIO.setwarnings(False)

def get_unix_time_as_string():
    unix_time = int(time.time())
    return str(unix_time)

def current_system_time():
    now = datetime.datetime.now()
    return now

def get_uptime():
    with open('/proc/uptime', 'r') as f:
        uptime_seconds = float(f.readline().split()[0])
        uptime_hours = (uptime_seconds/3600)
    uptime_hours = str(round(uptime_hours, 2))
    return uptime_hours

def get_temp():
    temp = os.popen('vcgencmd measure_temp').readline()
    temp= temp.replace("temp=","").replace("'C\n","")
    print("Pi Temp: " + str(temp) + " C")
    return temp

def send_data(event):
    message = (str(dev_id) + " " + str(event) + "\n" + "Uptime: " + str(uptime) + " hours\n" + "Batt: " + str(battery_voltage) + "V \n" + "Temp: " + str(temp) + " degrees" + "\nTime: " + str(now))
    print(message)

    print("This is where a user can implement interesting stuff.")
    print("You can write Python code or you can uncomment the example executing a binary below.")
    os.system("ls")
    #Please check out the github repo for more examples

def set_pin_state():
    GPIO.setmode(GPIO.BCM)

    GPIO.setup(START_PIN, GPIO.IN)
    GPIO.setup(DATA_PIN, GPIO.IN)
    GPIO.setup(CLOCK_PIN, GPIO.IN)

    GPIO.setup(ALIVE_PIN1, GPIO.OUT)
    GPIO.output(ALIVE_PIN1, 1)
    GPIO.setup(ALIVE_PIN2, GPIO.OUT)
    GPIO.output(ALIVE_PIN2, 0)

def shutdown_pin_state():
    GPIO.output(ALIVE_PIN1, 0)
    GPIO.output(ALIVE_PIN2, 1)

def check_internet_connection(hosts=["8.8.8.8", "1.1.1.1", "192.0.43.10"]):
    for host in hosts:
        try:
            result = subprocess.run(["ping", "-c", "1", "-W", "1", host], stdout=subprocess.DEVNULL,
stderr=subprocess.DEVNULL)
            if result.returncode == 0:
                return True
        except Exception as e:
            print(e)

    return False


def get_battery_voltage():
    # Receive and assemble the 16-bit value (MSB first)
    received_value = 0
    GPIO.wait_for_edge(START_PIN, GPIO.FALLING)
    for i in range(8):
        GPIO.wait_for_edge(CLOCK_PIN, GPIO.RISING)
        # Read the data bit from the DATA_PIN and update the received_value
        bit = GPIO.input(DATA_PIN)
        received_value = (received_value << 1) | bit# Wait for the clock to go low
        #print(bit, end="")
    return received_value

def get_average_battery_voltage():

    battery_voltages = []
    for i in range (5):
        battery_voltage = get_battery_voltage()
        #print(" " + str(battery_voltage))
        battery_voltages.append(battery_voltage)
    sorted_voltages = sorted(battery_voltages)
    #print(sorted_voltages)
    middle_idx = len(sorted_voltages) // 2
    median_value = (sorted_voltages[middle_idx - 1] + sorted_voltages[middle_idx]) / 2
    #print("The median value is:", median_value)
    median_value = round(median_value, 2)
    median_value = (median_value *2)/100
    return(median_value)

def is_battery_voltage_stable(voltage_list):

    #print("sum of voltages in list is: " + str(sum(voltage_list)))
    average = sum(voltage_list) / len(voltage_list)
    print("Vbatt avg: " + str(average))
    half = len(voltage_list) // 2
    first_half = voltage_list[:half]
    second_half = voltage_list[half:]

    first_half_average = sum(first_half) / len(first_half)
    second_half_average = sum(second_half) / len(second_half)
    #print("The average of the first half is: " + str(first_half_average))
    #print("The average of the second half is: " + str(second_half_average))

    if (first_half_average <= second_half_average):
        print("VBatt trending up")
        return True
    else:
        print("VBatt trending down")
        return False

set_pin_state()
GPIO.output(ALIVE_PIN1, 1)
GPIO.output(ALIVE_PIN2, 1)
first_boot = True
voltage_list =[]
time.sleep(10)
internet = check_internet_connection()
if (internet is True):
	print("Internet connection working")
else:
	print("Internet connection not working")

while True:

    try:
        now = datetime.datetime.now()
        dev_id = os.uname()[1]
        uptime = get_uptime()
        temp = get_temp()
        unix_time_string = get_unix_time_as_string()
        #print(unix_time_string)
        battery_voltage = get_average_battery_voltage()
        voltage_list.append(battery_voltage)
        #print(voltage_list)
        if ((len(voltage_list)) > 5):
            Vbatt_stability = is_battery_voltage_stable(voltage_list)
        print(str(battery_voltage) + "V")

        if shutdown_start_hour <= now.hour and now.hour < shutdown_end_hour: # this is legacy code, it should not shut down ever
            event = " Night time shutdown...  "
            send_data(event)
            print("Shutdown the Raspberry Pi")
            shutdown_pin_state()
            os.system("sudo shutdown now")

        elif (float(temp) > 75):
            event = " Temperature shutdown...  "
            send_data(event)
            # Shutdown the Raspberry Pi
            shutdown_pin_state()
            os.system("sudo shutdown now")

        elif (float(battery_voltage) < 3.5):
            print("Low Battery Voltage Detected, getting results in 5 seconds")
            time.sleep(5)
            battery_voltage = get_average_battery_voltage()
            if (float(battery_voltage) < 3.45):
                event = " Low Battery Voltage Shutdown...  "
                time.sleep(2)
                send_data(event)
                shutdown_pin_state()
                os.system("sudo shutdown now")
            else:
                print("The low battery voltage was temporary")

        elif (now.minute == 27):
            if (float(battery_voltage) > 3.8):
                event = "Normal Vbatt High"
                send_data(event)

            elif ((len(voltage_list)) > 5):
                V_batt_trend = is_battery_voltage_stable(voltage_list)
                if (V_batt_trend == True):
                    event = "Normal VBatt stable"
                    send_data(event)
                else:
                    event = "Normal VBatt falling shutting down"
                    send_data(event)
                    shutdown_pin_state()
                    os.system("sudo shutdown now")

            else:
                event = "Normal, VBatt trend pending"
                send_data(event)
            voltage_list =[]

        elif (first_boot == True):
            event = " Starting up "
            send_data(event)
            first_boot = False

        time.sleep(57)

    except:
        print("An error... ")
	#slowdown error to prevent temp increase    
        time.sleep(15)

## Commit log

2023-11-06 bulk upload
    [RPI_Pico_header_attiny84_with_solar_Test_Pads_r5.kicad_pcb, Revised_6W_Pannel_Mount.scad, case_interior_battery_cube_r4.scad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]
2024-01-10 Updates to FDM
    [Pannel_Mount_6W.scad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]
2024-01-10 Updates to FDM2
    [case_interior_battery_cube_r4.scad, case_interior_battery_cube_r5.scad]
2024-01-16 BOM changes
    [UPS_mount_r7.scad, case_mount_r7.scad, case_mount_r7.stl]
2024-01-16 BOM changes2
2024-01-16 BOM changes3
2024-01-16 BOM changes4
2024-01-16 BOM changes5
2024-01-16 BOM changes6
2024-01-16 BOM changes7
2024-01-17 Revert PCB
    [Photon_Power_Zero_PCB_r1-B_Cu.gbr, Photon_Power_Zero_PCB_r1-B_Mask.gbr, Photon_Power_Zero_PCB_r1-B_Paste.gbr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]
2024-01-18 numerous changes
    [Photon_Power_Zero_PCB_r1.kicad_pcb, UPS_mount_r7.scad, case_mount_r7.scad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]
2024-02-18 Scad Updates
    [UPS_mount_r7.scad, UPS_mount_r8.scad, UPS_mount_r8.stl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]
2024-02-26 kicad cleanup
    [RPI_Pico_header_attiny84_with_solar_Test_Pads_r5.kicad_pcb]
2024-02-28 LiPo Considerations
2024-03-04 Added schematic r1 informational only
    [PhotonPowerZeroSchematic_Informational_Only.kicad_sch]
2024-03-05 Schematic Udate
    [PhotonPowerZeroSchematic_Informational_Only.kicad_sch]
2024-03-13 LiPo docs update
2024-03-13 LiPo docs update2
2024-03-19 minor pcb and schematic updates!
    [PhotonPowerZeroSchematic_Informational_Only.kicad_sch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]
2024-03-19 Rotated PCB
    [Photon_Power_Zero_PCB_r1.kicad_pcb]
2024-03-21 Minor Updates
    [UPS_mount_r8.stl, UPS_mount_r9.scad, UPS_mount_r9.stl]
2024-04-04 misc update
    [UPS_mount_r10.scad, UPS_mount_r10.stl]
2024-04-04 code changes
    [UPS_mount.scad, UPS_mount_r10.scad, UPS_mount_r10.stl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]
2024-04-05 FDM docs correction
    [UPS_mount_r10.scad, UPS_mount_r10.stl]
2024-04-09 Visual PCB revisions
    [Photon_Power_Zero_PCB_r1_01.kicad_pcb]
2024-04-10 Minor PCB changes
    [Photon_Power_Zero_PCB_r1_01.kicad_pcb]
2024-04-23 Organising FDM
    [Panel_Mount_6W.scad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]
2024-04-23 FDM updates
    [Jaycar_case_mount_r9.stl, Panel_Mount_6W.stl, Pole_mount.stl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]
2024-04-24 Enclosure links and Update
2024-04-24 Enclosure links and Updates 2
    [Jaycar_case_mount_r9.stl, Panel_Mount_6W.scad, Panel_Mount_6W.stl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]
2024-04-24 Enclosure links and Updates 3
2024-04-24 Enclosure links and Updates 4
2024-05-14 minor revs
    [Photon_Power_Zero_PCB_r1_01-B_Cu.gbr, Photon_Power_Zero_PCB_r1_01-B_Mask.gbr, Photon_Power_Zero_PCB_r1_01-B_Paste.gbr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]
2024-05-19 docs update lipo battery stuff
2024-06-09 Update PPZ_RPi_code.py - slowdown exepction
    I was getting an exception on first boot. As there is no timeout the error filled the screen with the current temp and increased the temperature of the pi.
    [PPZ_RPi_code.py]
2024-06-11 minor docs update
    [Photon_Power_Zero_PCB_r1_02.kicad_pcb]
2024-06-20 Update PPZ_RPi_code.py
    spaces not tabs to clear error on line 217
    [PPZ_RPi_code.py]
2024-07-03 new enclosure
    [Jaycar_case_mount_r9.stl, Panel_Mount_10W.scad, Panel_Mount_10W.stl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]
2024-07-03 new enclosure readme
2024-07-03 new enclosure readme2
2024-07-03 new enclosure readme3
2024-07-03 new enclosure readme4
2024-07-03 new enclosure readme5
2024-07-08 10W Solar Panel Documentation
    [Panel_Mount_10W.scad, Panel_Mount_10W.stl, Panel_Mount_10W_1st_half.stl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]
2024-08-05 10W docs update
    [Jaycar_case_mount_r10.stl, Panel_Mount_10W_1st_half.stl, Panel_Mount_10W_2nd_half.stl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]
2024-08-11 major docs update
    [Panel_Mount_10W_1st_half.stl, Panel_Mount_10W_2nd_half.stl, Panel_Mount_10W_r2.scad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]
2024-08-13 Docs Update=
    [case_mount_r10.scad]
2024-08-19 Wireless Interfaces Doc start
2024-08-25 image switch
2024-08-27 Docs and Images
    [UPS_mount_r11.scad, UPS_mount_r11.stl]
2024-09-17 experimental PCBs
    [RFM69HCW_v03.kicad_pcb]
2024-10-31 RFM69 code
    [RFM69HCW_v5-B_Cu.gbr, RFM69HCW_v5-B_Mask.gbr, RFM69HCW_v5-B_Paste.gbr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]
2024-11-04 PCB rev
    [RFM69HCW_v6.kicad_pcb]
2024-12-05 PCB update
    [RFM69HCW_v7-B_Cu.gbr, RFM69HCW_v7-B_Mask.gbr, RFM69HCW_v7-B_Paste.gbr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]
2025-07-15 changes for rev2 and cleanup
    [Photon_Power_Zero_PCB_r1_01.kicad_pcb, Photon_Power_Zero_PCB_r1_02.kicad_pcb, RFM69HCW_v03.kicad_pcb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]
